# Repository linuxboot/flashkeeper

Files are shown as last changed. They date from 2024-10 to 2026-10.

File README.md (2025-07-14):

# Flashkeeper

## Manage and Protect your SPI Flash Chip!

[Documentation](https://flashkeeper.org) | [Source](https://git.15h.org/Flashkeeper/flashkeeper) | [Join us on Matrix!](https://matrix.to/#/#flashkeeper:matrix.org)

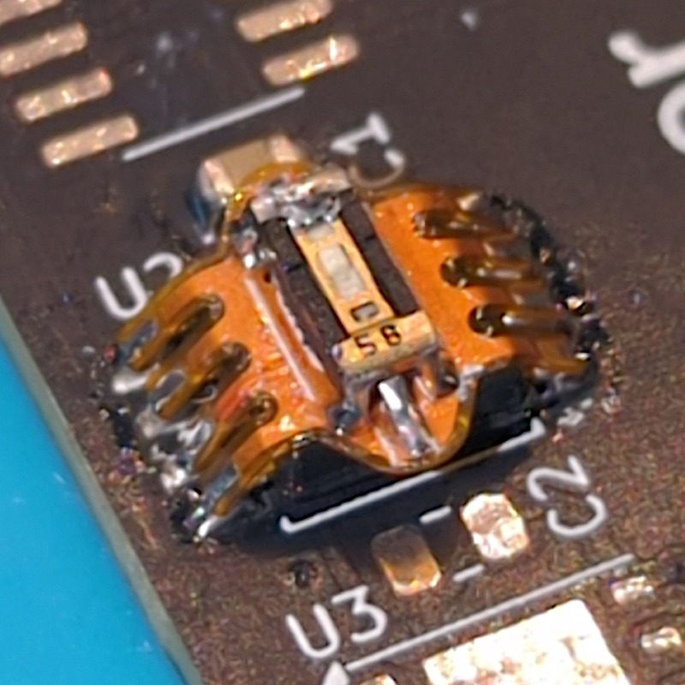
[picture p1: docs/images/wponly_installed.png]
A Flashkeeper WP provides a write-protection control switch on top of a SOIC-8 flash chip


Flashkeeper is a family of open-hardware add-ons for standard SOIC-8 and WSON-8 SPI NOR flash chips (as are commonly used for firmware storage in PCs and other electronics), providing functionality for write-protection control, SPI bus breakout, flash device emulation, reprogramming, and state validation.

Flashkeeper development takes place on the [15h.org](https://15h.org) Git forge, and is mirrored to Github as a backup. If you wish to participate in Flashkeeper development on 15h.org infrastructure, please request an account in either the [Flashkeeper room](https://matrix.to/#/#flashkeeper:matrix.org) or the 15h.org room on Matrix. Issues may be opened on either 15h.org or Github.

For user information, please see the [documentation](https://flashkeeper.org). For hardware source files, see `hw/`.

The Flashkeeper project is supported by [NLnet NGI Zero Core](https://nlnet.nl/project/Flashkeeper/).

---

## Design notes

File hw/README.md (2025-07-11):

# Flashkeeper Hardware
For source of the Flashkeeper website, see https://github.com/linuxboot/flashkeeper.

`adapter_soldered`: KiCAD files for the soldered Flashkeeper chip adapter

`dummy_board`: Rigid PCB with multiple flash package footprints and connectors for testing and development

`spispy_board`: FPGA-SoM-based board to run `spispy` during development

`single_stencil`: Project containing all PCBs in a single file. Intended to export a single paste-layer Gerber so that all Flashkeeper boards can be made using different parts of a single solder paste stencil.

`CAD`: FreeCAD files for Flashkeeper mechanical components

`flashkeeper.kicad_sym`: Symbol library for components used in Flashkeeper

`flashkeeper.pretty`: Footprint library for components used in Flashkeeper

KiCAD and FreeCAD files are for the latest upstream versions of KiCAD and FreeCAD, as of the last modification of that file. Depending on which versions your OS's packages ship, on some platforms (like Debian), this may mean installing from another repository (e.g. Debian Backports), or using an alternative packaging system such as Flatpak or AppImage. Please follow the installation instructions for your platform here:

- https://www.kicad.org/download/

- https://www.freecad.org/downloads.php

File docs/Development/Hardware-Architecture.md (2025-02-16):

---
layout: default
title: Hardware Architecture
permalink: /Hardware-Architecture/
nav_order: 99
parent: Development
---

Hardware Architecture
{: .fs-8 .m-0 }

Flashkeeper's hardware is a modular system, able to be configured for a variety of SPI flash chip security, debugging, and management tasks. Depending on their goals, most users will not need to use every part of the system. This page lists and describes the components of the Flashkeeper system, as well as the major electronic components selected for use in them, and describes some practical combinations of different Flashkeeper components. Much of this document describes "feasibility and selection" research completed before work on Flashkeeper hardware in earnest had begun - as such, it may refer to work already performed (i.e. design of various chip adapters) in the future tense.

<!-- markdownlint-disable MD033 -->
 <details open markdown="block">
   <summary>
     Table of contents
   </summary>
   {: .text-delta }
 1. TOC
 {:toc}
 </details>
 <!-- markdownlint-enable MD033 -->

Components
---
### Chip Adapter

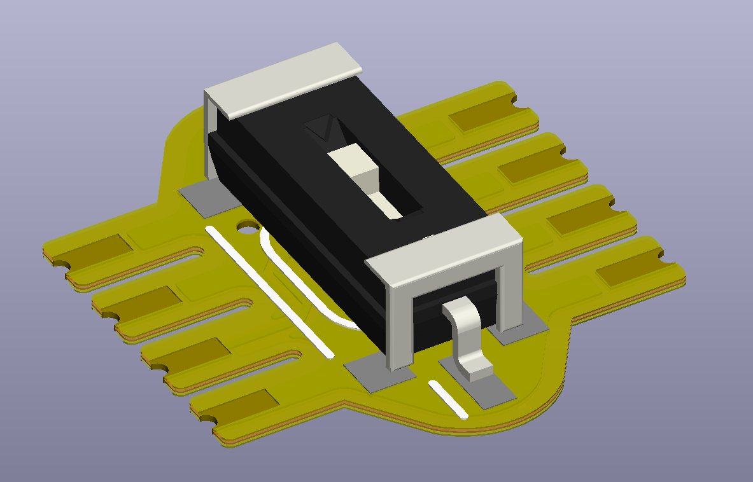
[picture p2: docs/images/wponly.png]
design


A small flex PCB which installs semi-permanently on top of an SPI flash chip. Provides control over write protection, and a breakout of the SPI bus to external devices. A flash adapter can be:

- Soldered or Solderless
- SOIC-8, WSON-8, SOIC-16, or DIP (SOIC-8 and WSON-8 are the priorities at this time, due to being the most common types)
- WP-only (providing only a switch or a jumper for write-protect control) or Breakout (with a ZIF socket, for all other uses)

As the chip adapter is electrically very simple, across all chip adapter variants, only a handful of components need to be selected:

- DIP switch for WP variants: Nidec CVS-01TB (seemingly the smallest, lowest-profile single DIP switch available)
- Spring-loaded contact for solderless variants: Harwin P70-7000045 (a rare example of a low-profile spring-loaded contact small enough to fit in a 1.27mm pitch)
- Connector for Breakout variants: TBD

### Flex Cable
A simple straight-through flex cable which runs from Breakout variants of the chip adapter to other devices, inside or outside the chassis. Connectors should be selected such that commercially-available cables can be used.

### External Breakout Board
A board intended for use outside the system, connected to the breakout cable. Useful to connect your SPI flash chip to to devices including:

- External flash programmers (e.g. CH341a), for conventional flashing/unbricking
- Development hardware such as logic analyzers or external (i.e. not the Flashkeeper FPGA Board) FPGA hardware
- The External Flash Emulator

It also allows an alternate use of the flex able, interfacing with the Flashkeeper FPGA board, as opposed to the Chip Adapter. In this role, it can be used as a USB interface board for the FPGA board, for FPGA development and authenticated reprogramming.

### External Flash Emulator
The External Flash Emulator is a development tool intended to be connected to the breakout Chip Adapter via the flex cable. It runs SPIspy and has enough memory to fully emulate the SPI flash chip, and is intended primarily as a development/diagnostic tool.

### Flashkeeper FPGA Board
The Flashkeeper FPGA is a (very) small board using the Lattice iCE40UP5K, to be installed inside the system. It provides authenticated external reprogramming (via the breakout board), and can also be used to verify flash contents in-situ (similar to the functionality of Intel's Boot Guard, but under user control). Major components of the FPGA board include:

- FPGA: Lattice iCE40UP5K-UWG30
- 1.2V Voltage Regulator: TI TPS7A2012PYCJR
- 1.8V Voltage Regulator: onsemi NCP110AFCT180T2G
- FPGA Flash Chip (firmware only - gateware burned to NVCM): BYTe BY25Q20BLRIG(R)
- Connector: Integrated flex PCB edge connector (goes into chip adapter)

It also would be possible to implement an FPGA board that was itself part of a chip adapter. This would likely reduce overall size (avoiding the connector), and situate the FPGA closer to the flash chip itself (possibly assisting some physical security mitigations), but it would of course require more permutations of FPGA boards. For now, it's not the plan.

Modularity
---
Practical configurations of Flashkeeper hardware, and their applications, include:

- Chip adapter only (either type - soldered or solderless)
	+ Add write-protection control to a flash chip on a board which does not have one
	+ Enforce partial write-protection (e.g. for Coreboot bootblock only) while allowing the remainder of flash to be updated
- Chip adapter, flex cable, breakout board
	+ Chip adapter only features
	+ Connect an external programmer (e.g. CH341a) to flash, read flashconsole, etc, without disassembling system
	+ Debug SPI with a logic analyzer
- Chip adapter, flex cable, breakout board, external flash emulator
	+ Run SPISpy (full-memory external flash emulator)
		* Rapidly-reprogrammable emulated flash for development
		* "tcpdump-style" debugging
		* Security experiments (e.g. ME TOCTOU)
- Chip adapter, Flashkeeper FPGA board, flex cable, breakout board
	+ Flashkeeper FPGA development
	+ Authenticated external reprogramming (FPGA authenticates rewriting the flash chip against a user key it holds)
- Chip adapter, Flashkeeper FPGA board (no breakout)
	+ Boot-time firmware verification
	
Depending on a user's goals, they are unlikely to require all of these configurations, and so may want to use only some components of the Flashkeeper hardware ecosystem.

Mechanical Design
---
Most Flashkeeper hardware is relatively conventional mechanically, apart from the severe size constraints on hardware inside the chassis. It consists mostly of ordinary rigid and flex PCBs. The exception to this is the solderless chip adapter, which needs to maintain contact with the _top_ of its flash chip's legs, without soldering, in a reliably-installable way. 

Without resorting to custom-designed-and-manufactured contacts, we're left with few options. The most practical, as far as we can tell, is the Harwin P70-7000045. It fits - it's low-profile, and it's narrow enough to fit into the 1.27mm lead pitch of common SMT flash chip packages, but it's a tight squeeze. 

The plan is to solder eight such contacts (each themselves a surface-mount part) to a thin rigid PCB, precisely-aligned. To assist repeatability, and to avoid contact between adjacent contacts (as the gap between them is nominally only 0.21 mm), we've designed a machined aluminum alignment block, with 8 holes drilled in the correct pattern, which can hold the pins in place, then be removed after soldering. After the alignment block is removed, a 3D-printed "adapter body" can then be pressed down over the pins and attached with adhesive to the "bottom" of the adapter PCB, around where the contacts are joined to it. This adapter body serves to insulate the contacts from eachother, and to hold them in alignment above the chip legs. It will need to be SLA 3D-printed at high resolution.

The rigid PCB should then be able to be designed much like the soldered adapter's flex PCB, with either a breakout connector, or a WP control switch.

To attach the solderless adapter to the top of the flash chip, a peel-and-stick adhesive layer will need to be applied to the bottom of the adapter body. Attachment to the flash chip relies on this layer properly adhering the adapter to the top of the flash chip, against the spring force of its contacts. It will be important to instruct the user on the proper cleaning of their flash chip, and on the proper application of the adapter. For example, installation repeatability could be aided by a 3D-printable handheld plunger-style force gauge, helping the user apply the right amount of force to the adhesive for the right duration to adhere it properly without risk of damage.

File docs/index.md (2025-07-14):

---
layout: default
title: Home
has_children: true
has_toc: false
permalink: /
nav_order: 1
---

# Manage and Protect your SPI Flash Chip!

Flashkeeper is a family of open-hardware add-ons for standard SOIC-8 and WSON-8 SPI NOR flash chips (as are commonly used for firmware storage in PCs and other electronics), providing functionality for write-protection control, SPI bus breakout, flash device emulation, reprogramming, and state validation.

wponly
*The WP-only adapter provides a physical write protection switch for [flash chips supporting WP](https://github.com/linuxboot/flashkeeper/pull/14/files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)*

<!-- markdownlint-disable MD033 -->
<details open markdown="block">
  <summary>
    Table of Contents
  </summary>
  {: .text-delta }
1. TOC
{:toc}
</details>
<!-- markdownlint-enable MD033 -->

## For Users
Flashkeeper is a modular family of several related devices - to find out which components you need, and where to get them, see [Getting Started](/Getting-Started).

## For Developers
Flashkeeper development takes place on the [15h.org](https://15h.org) Git forge, and is mirrored to Github as a backup. If you wish to participate in Flashkeeper development on 15h.org infrastructure, please request an account in either the [Flashkeeper room](https://matrix.to/#/#flashkeeper:matrix.org) or the 15h.org room on Matrix. Issues may be opened on either 15h.org or Github.

## More about Flashkeeper

* [Flashkeeper threat model]({{ site.baseurl }}/Flashkeeper-threat-model/) - goes into more detail about what classes of threats Flashkeeper attempts to counter.
* [Frequently Asked Questions]({{ site.baseurl }}/FAQ/)
* [Prior Art/State of the Art prior of project start](https://cfp.3mdeb.com/qubes-os-summit-2024/talk/FCENX9/)

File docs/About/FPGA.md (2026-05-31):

---
layout: default
title: FPGA Module
permalink: /FPGA
nav_order: 9
has_children: no
has_toc: true
---

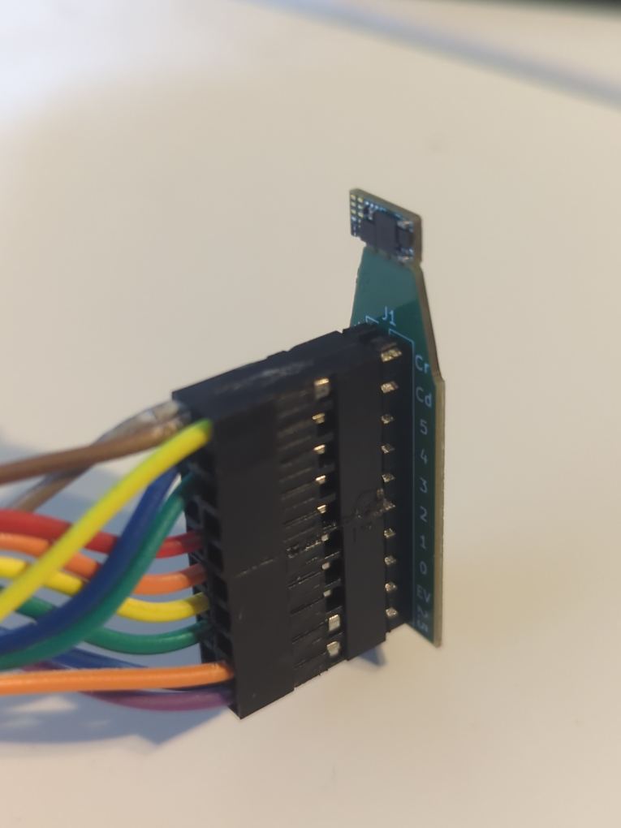
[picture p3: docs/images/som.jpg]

*The Flashkeeper SoM (top), attached to its removable breakout tab with a standard 2.54mm pin header*

# Introduction
The Flashkeeper FPGA module is special variant of the Flashkeeper chip adapter, designed to interface your SPI flash chip with a specialized Flashkeeper system-on-module (SoM) based on a Lattice iCE40UP5K FPGA. The Flashkeeper FPGA module is a general-purpose computer, under full, RTL-level user control, and designed for a wide range of security, development, and flash device management tasks. In addition to its RISC-V soft core and the hardware reconfigurability afforded by any FPGA, it also features 4 Mbit of NOR flash, 128 kB of main SRAM, one-time programmable NVCM, flexible SPI, UART, and I2C peripherals, a software-controllable buzzer for alerts and acoustic communications, an integrated real-time clock with battery and crystal, and onboard power regulation and filtering for all required voltage rails, including battery charging, from the single power rail on the host flash chip package.

<!-- markdownlint-disable MD033 -->
<details open markdown="block">
  <summary>
    Table of Contents
  </summary>
  {: .text-delta }
1. TOC
{:toc}
</details>
<!-- markdownlint-enable MD033 -->

## System Compatibility
The Flashkeeper FPGA module is designed for use on most standard 8-pin NOR flash packages, including most SOIC-8 and WSON-8 variants. The module body, excluding its attachment legs, measures 4.7 x 7.5 mm, and the entire module, when fully folded, stands 6.0mm above the surface of the host flash chip, including its "tail" section (which contains the battery, buzzer, and associated components). In many systems, it can be installed in this folded configuration, with a footprint only negligibly larger than the flash chip itself. Unfolded, it requires only 2.6mm of vertical space above the flash chip, allowing the tail to sit beside the host flash chip.

The folded configuration is recommended for:
* Nearly all desktop and server platforms
* Laptops with sufficient space between motherboard and chassis
* Open-air usage (SBCs, development boards, bench testing, etc)

The unfolded configuration is recommended for: 
* Small-form-factor desktop systems with back-mounted SPI flash chips
* Most laptops - fit checks have been performed on various Lenovo ThinkPad X-series (including X220, X230, X140e)
* Systems where the debug ribbon cable is to remain easily-removable (for external flashing, wired verification, development, etc)

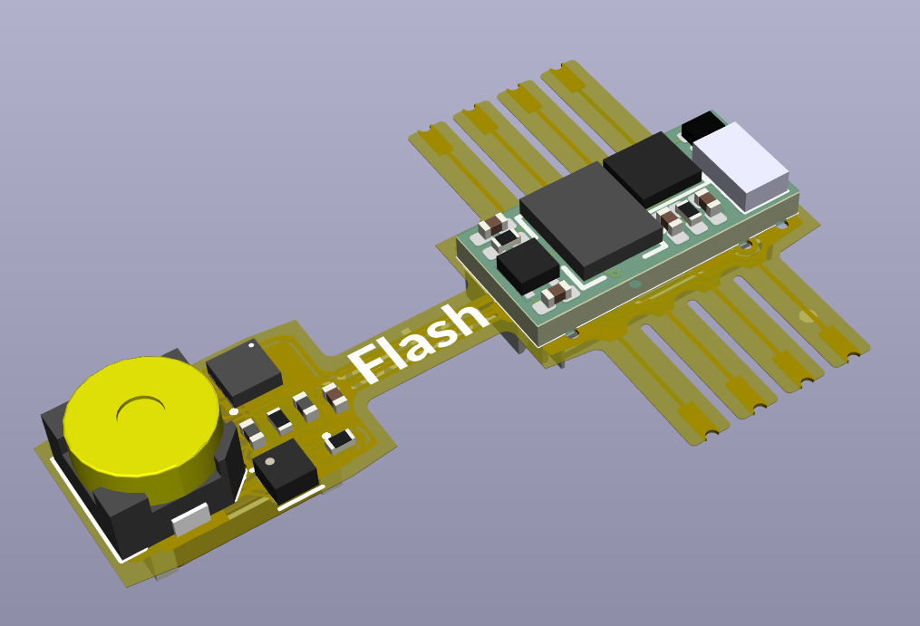
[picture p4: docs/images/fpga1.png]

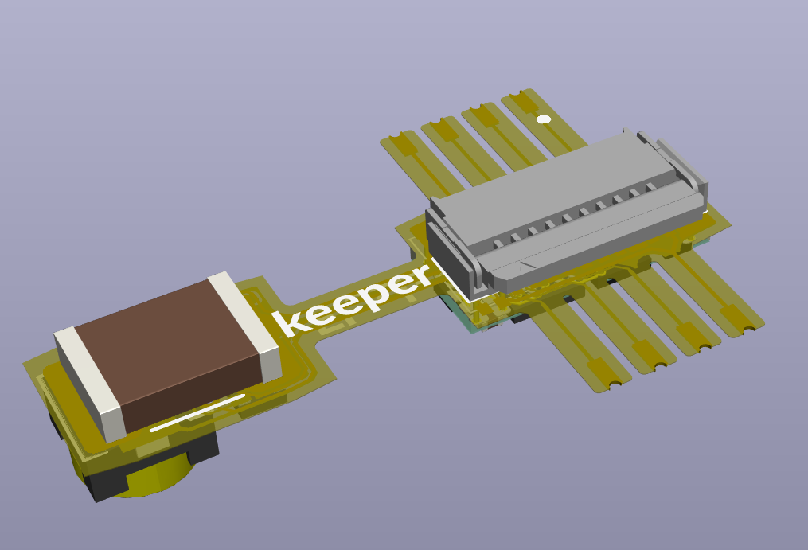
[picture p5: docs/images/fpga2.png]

*The tail section (left) can be folded over the chip adapter body (right), or can be laid to the side, depending on chassis or board obstructions*

The Flashkeeper FPGA draws approximately 9 mA while running, and can be installed with negligible power or thermal impact in virtually any computing device with a SOIC or WSON flash chip - for comparison, many SPI flash chips themselves can consume up to 25 mA while being erased and programmed during a firmware update. All systems we have evaluated for this have had more-than-sufficient current for the module available at the flash package.

The FPGA is only powered when the host SPI flash is, and should not meaningfully contribute to system battery drain in storage. When the host is powered on, Flashkeeper's real-time clock battery is trickle-charged by a dedicated low-power charging circuit. In order keep the RTC battery charged, host systems should be powered on for at least 2-3 hours per month if Flashkeeper's real-time clock is required. A diode prevents the RTC battery from discharging into the rest of the SoM, or into the host, when host power is unavailable.

On systems using 1.8V SPI flash, the module is able to generate most of its voltages from 1.8V, but the FPGA itself requires a 2.5-3.3V rail for its internal oscillator and one-time programmable memory. Even on systems with 1.8V flash, 3.3V power is usually available nearby on the motherboard and can be relatively easily wired to the module during installation - a solder jumper and designated pad on the module are provided for this use.

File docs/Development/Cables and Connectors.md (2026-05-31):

---
layout: default
title: Cables and Connectors
permalink: /Cables-Connectors/
nav_order: 99
parent: Development
---

Cables and Connectors
{: .fs-8 .m-0 }

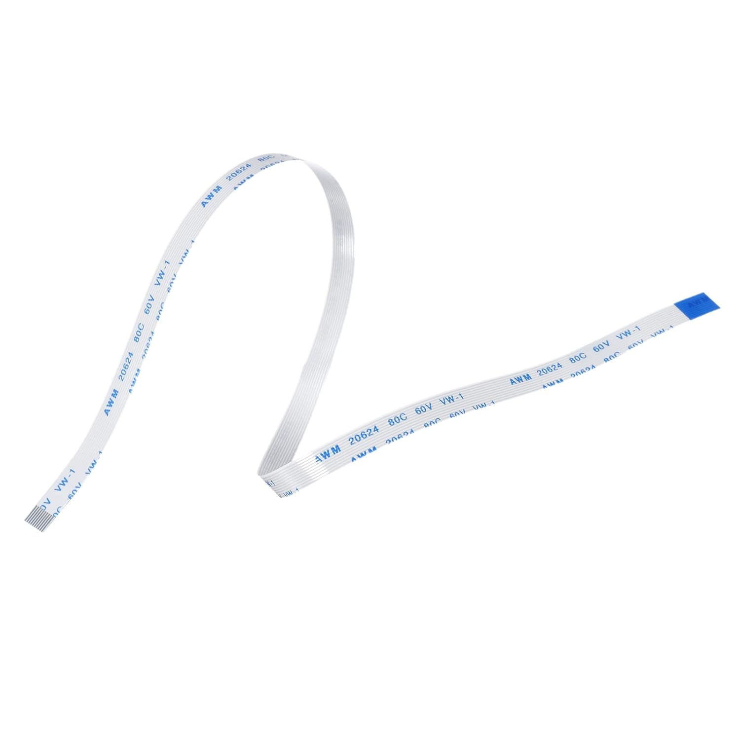
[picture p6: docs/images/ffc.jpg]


Flashkeeper has standardized on two common types of flat-flex cable (FFC) - one for Flashkeeper FPGA hardware, one for breakout chip adapters. All FFCs used by Flashkeeper are standard 0.5mm pitch B-type (opposite-side-contact) cables, as are commonly used in laptops and other consumer electronics. Lengths between 1cm and 50cm are widely and inexpensively available online from websites such as [AliExpress](https://www.aliexpress.com/w/wholesale-0.5mm-b%2525252dtype-ffc.html?spm=a2g0o.productlist.search.0), [eBay](https://www.ebay.com/sch/i.html?_nkw=0.5mm+b+type+ffc), and [Amazon](https://www.amazon.com/s?k=0.5mm+b+type+ffc), and are generally interchangeable between brands. If purchasing FFCs for Flashkeeper hardware, for best signal integrity, opt for the shortest cable which will reach in your chassis.

While both are common sizes, note that cables are NOT interchangeable between Flashkeeper breakout chip adapters (including dummy boards), and Flashkeeper FPGA hardware - these devices carry different signals over different pinouts, and the FPGA hardware requires additional pins for use with the FPGA Configuration Tool.

<!-- markdownlint-disable MD033 -->
 <details open markdown="block">
   <summary>
     Table of contents
   </summary>
   {: .text-delta }
 1. TOC
 {:toc}
 </details>
 <!-- markdownlint-enable MD033 -->

---
### Breakout Chip Adapters
Flashkeeper FPGA hardware uses standard **8-pin** 0.5mm FFC, and has standardized on the TE Connectivity 2328702-8 flip-lock connector. If you wish to design flash device breakout hardware to be interoperable with Flashkeeper breakout hardware, the pinout is provided below - note that "pin 11" refers to the front grounding tabs of the connector, and does not appear on the cable itself.

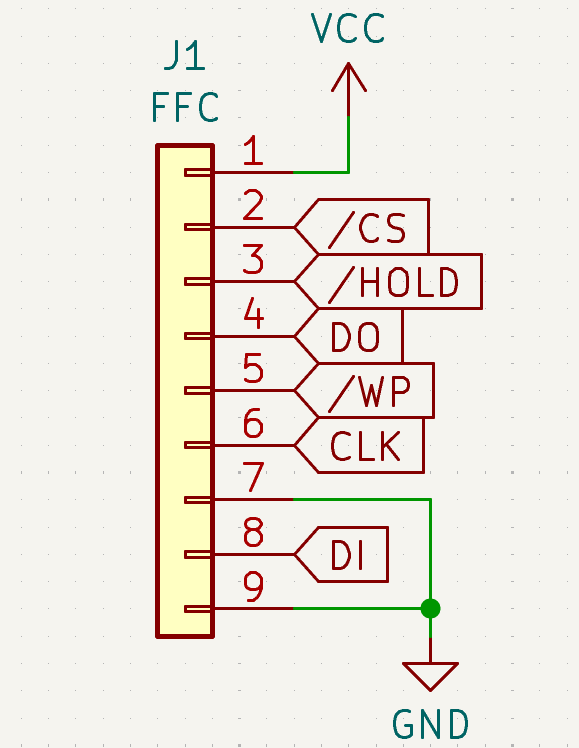
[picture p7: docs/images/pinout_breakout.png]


### FPGA Hardware
Flashkeeper FPGA hardware uses standard **10-pin** 0.5mm FFC, and has standardized on the TE Connectivity 1-2328702-0 flip-lock connector. If you wish to design sensors, adapters, or other peripherals to be interoperable with Flashkeeper FPGA hardware, the pinout is provided below - note that "pin 9" refers to the front grounding tabs of the connector, and does not appear on the cable itself.

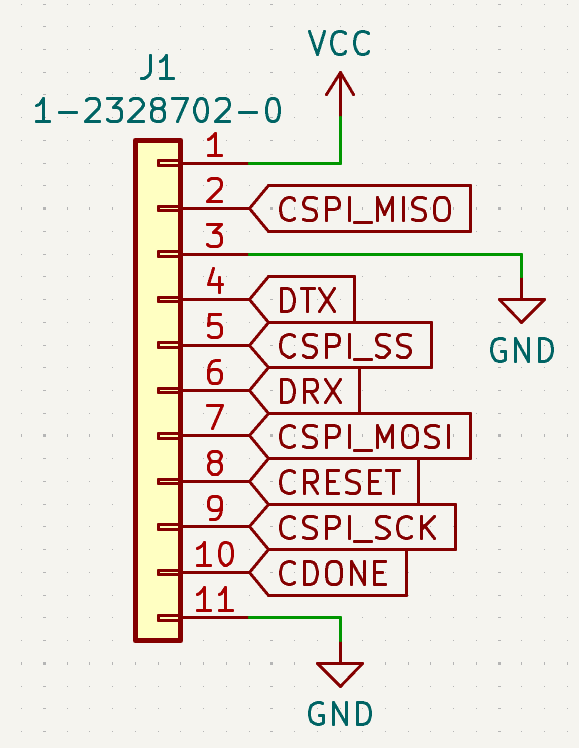
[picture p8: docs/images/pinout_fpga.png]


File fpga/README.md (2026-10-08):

# Flashkeeper FPGA

Gateware and firmware for the iCE40UP5K FPGA on the Flashkeeper FPGA module, using PicoSoC and the PicoRV32 RISC-V core.

For KiCAD source for the Flashkeeper FPGA hardware, see hw/fpga

## SoC Features
- PicoRV32 RV32IZmmul CPU - hardware multiply, software divide (picorv32.v)
- Modified PicoSoC (picosoc.v)
- 128 KiB RAM (iCE40UP5k SPRAM - ice40up5k_spram.v)
- EBR-based bitstream Boot ROM (can be OTP-programmed as part of NVCM - ebrrom.v)
- Configuration (CSPI) and Host (HSPI) SPI flash interfaces (spimemio.v)
- Buffered UART serial interface (uart.v)
- Entropy source for TRNG (rng.v)
- On-chip (HFOSC) clock source for crystal-less Flashkeeper FPGA SoM (top.v)

## Firmware Features
- Forth-like Embedded Debug Environment shell (ede.h)
- Diagnostics and flash device management via serial interface (type help at EDE)
- Boot-ROM-based firmware loading and verification from flash (rom/)
- Cryptography provided by TweetNaCl (tweetnacl.c)
- High-speed libsodium-based ed25519 verifcation (fwsiglib)
- Serial password authentication support (main.c - password_prompt, generate_password)
- flashrom-compatible serprog emulation mode (serprog.c)
- Software-based entropy extraction and RNG monitoring (rng.c)

## Build Dependencies
On Debian, install:
```
sudo apt install yosys nextpnr-ice40 fpga-icestorm gcc-riscv64-unknown-elf
```

## Building and Flashing
To build an image for the Flashkeeper SoM development kit, run `make som_image`. To flash it to the SoM using flashrom
and a standard CH341a SPI flash programmer, run `make prog_flash_som`. During flashing, this target will attempt to hold
the FPGA in reset using an ESP-PROG (which can be used as a USB serial interface for a standalone Flashkeeper SoM).

Targets and pin mappings are also provided for use with the official Lattice iCE40 UltraPlus Breakout Board (iCE40UP5K-B-EVN),
which has an onboard FT2232HL-based debug interface. To program this board using iceprog, run `make prog_flash_breakout`.

## Firmware Signing
By default, these Makefiles will attempt to generate a signed firmware image, and will enable firmware signature verification in the
Boot ROM. This requires a keypair to sign your firmware image - you can generate one with:
```
make -C firmware tools/genkey
firmware/tools/genkey firmware/keys/pk.key firmware/keys/sk.key
```
After generating your keypair, the build will automatically sign your firmware using your secret key (sk.key), and your built Boot ROM
will automatically include your public key (pk.key) and use it to verify your signed firmware images at boot.

If you wish to build an *unsigned* firmware image, you can build with `SIGN=0`. By default, the Boot ROM will reject unsigned images - to
build a Boot ROM allowing unsigned images, also build with `ROM_ALLOW_UNSIGNED=1`. For example, to build an unsigned image and a Boot ROM
that will accept it, for the Flashkeeper FPGA SoM, you can run:
```
make som_image SIGN=0 ROM_ALLOW_UNSIGNED=1
```
Of course, a boot ROM built with ROM_ALLOW_UNSIGNED provides **no protection against firmware tampering**, and should be used for development
only. A ROM_ALLOW_UNSIGNED Boot ROM can still boot signed firmware images (in addition to unsigned ones), and will still attempt to verify
a firmware image signature if one is present. 

## Setting a Password
If you are using a Flashkeeper FPGA in a deployed system, we strongly recommend setting a serial password - if you do not do so,
anyone able to connect to your FPGA's UART interface can read and write both Host (your computer's) and Configuration (your Flashkeeper's)
SPI flash devices.

By default, a password is required (SERIAL_REQUIRE_PASSWORD = 1), and the default password is `flashkeeper`.
If SERIAL_REQUIRE_PASSWORD is set to 0, the FPGA will enter EDE automatically at firmware boot (with a warning to set a password).

To set a password, run `genpw` at the Flashkeeper EDE shell (connected over serial), then copy-and-paste the resulting two lines into
firmware/flashkeeper_config.h, then rebuild and reflash your Flashkeeper firmware image (as described above).

## Boot Process
The Flashkeeper FPGA SoM has its own onboard 4 Mbit (512 kB) SPI flash chip (CSPI), which holds its FPGA bitstream and firmware.
The RISC-V reset vector and early boot is in boot ROM (in the FPGA's EBR, preloaded as part of the FPGA bitstream). The ROM is
firmware-independent (the image header in flash describes the image, so the ROM should not need to be rebuilt for firmware
changes). The Boot ROM's boot and firmware verification process is as follows:
- Load the firmware image from CSPI flash into RAM
- Confirm its IMG_MAGIC and size are valid
- Load a binary called fwsiglib from an extra region of CSPI flash after the firmware image, into a reserved SPRAM region below the stack
- Using TweetNaCl's SHA-512 (small enough to fit in the boot ROM), verify the hash of the fwsiglib binary against a hash built into the boot ROM
- If fwsiglib is valid, check if the loaded firmware image claims to be signed by the right public key
- Hash the firmware image in RAM's payload
- Using fwsiglib, check the firmware image's embedded ed25519 signature of its header and payload hash against its actual header and payload hash
- If correct, jump to the image's payload entry point.

## Licensing
Unless stated otherwise, developments of the Flashkeeper project are licensed under the GNU General Public License
Version 3.

serprog.c and serprog.h are derived from pico-serprog, developed by Mate Kukri and originally based on code by Thomas Roth.
pico-serprog is also licensed under the GNU General Public License Version 3.

Files originating with the PicoRV32 are under the ISC License. They were originally developed by Claire Xenia Wolf. picosoc.v,
spimemio.v, uart.v, and ice40up5k_spram.v have been modified as part of the Flashkeeper project.

memops.S, used for certain RISC-V memory operations, is under the 2-clause BSD license and was developed by Alexander Vysokovskikh.

libsodium ed25519 files used in the boot ed25519 library (rom/lib) are under the ISC license, and are developed by Frank Denis and
the [libsodium authors](https://raw.githubusercontent.com/jedisct1/libsodium/refs/heads/master/AUTHORS).

tweetnacl.c and tweetnacl.h are a public-domain cryptography library, and were developed by Daniel J. Bernstein,
Bernard van Gastel, Wesley Janssen, Tanja Lange, Peter Schwabe, and Sjaak Smetsers.

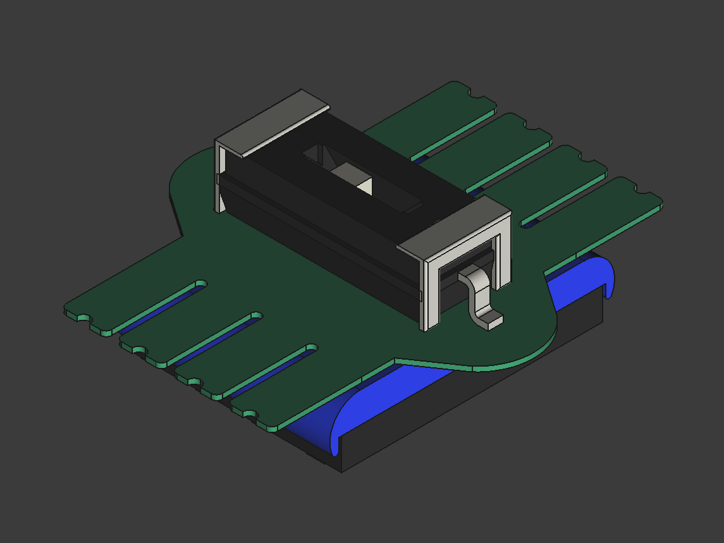
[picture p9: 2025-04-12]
docs/images/wson.png

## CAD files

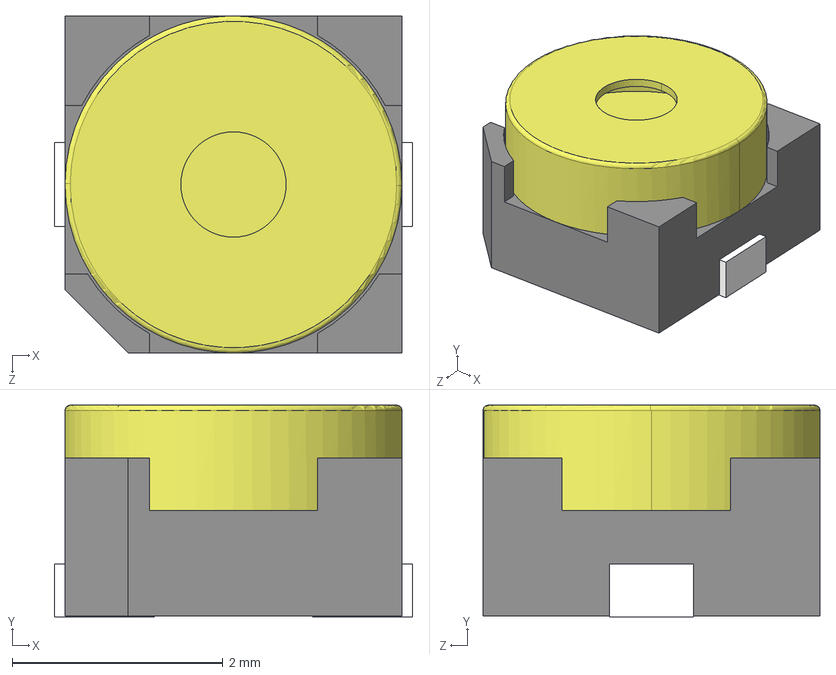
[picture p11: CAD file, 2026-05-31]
hw/CAD/CMT-322-65-SMT-TR.step
3.40 x 2.01 x 3.20 mm

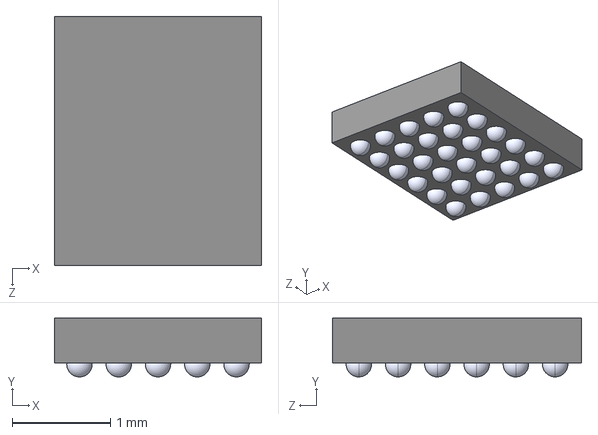
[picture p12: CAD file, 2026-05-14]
hw/fpga/ICE40UP5K-UWG30ITR/ICE40UP5K-UWG30ITR.step
2.11 x 0.6 x 2.54 mm

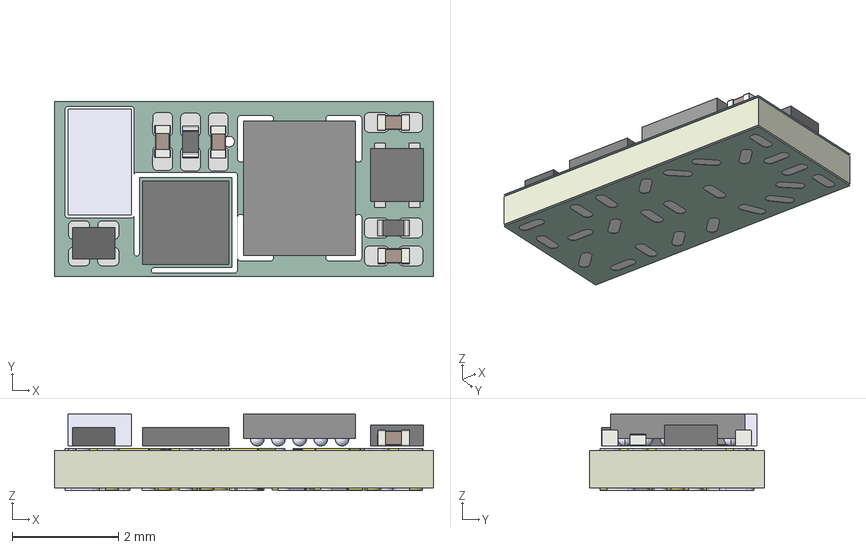
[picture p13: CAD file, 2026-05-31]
hw/CAD/FlashkeeperFPGASoM.step
7.15 x 3.30 x 1.45 mm
C_0201_0603Metric x 4
R_0201_0603Metric x 2
ICE40UP5K-UWG30ITR
fpga_notab_copper
fpga_notab_pad
fpga_notab_via
fpga_notab_silkscreen
fpga_notab_soldermask x 2
fpga_notab_PCB

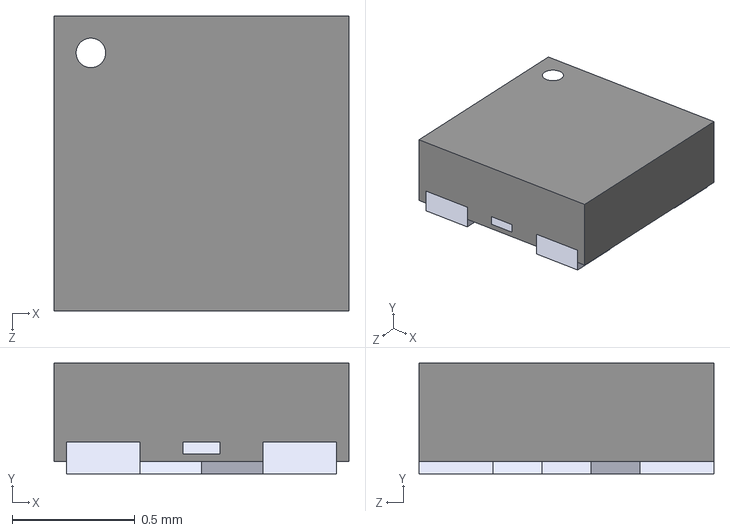
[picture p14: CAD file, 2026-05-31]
hw/CAD/NCP171AMX165160TCG.step
1.20 x 0.45 x 1.20 mm

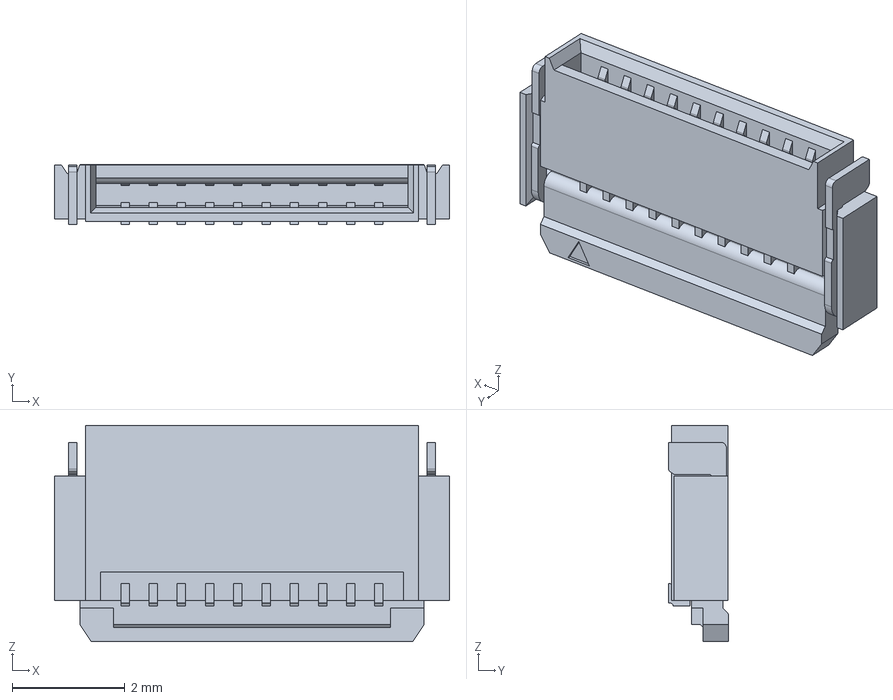
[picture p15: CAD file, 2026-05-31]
hw/CAD/1-2328702-0.STEP
7.00 x 1.06 x 3.83 mm

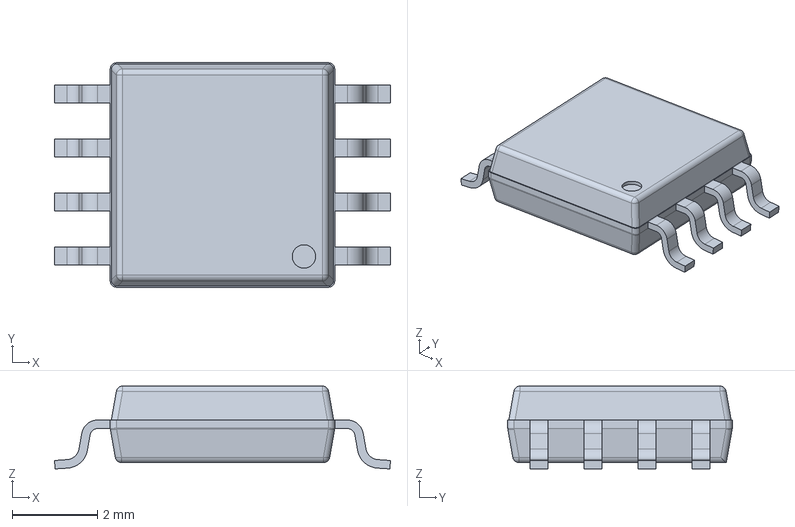
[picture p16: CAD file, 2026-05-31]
hw/CAD/SOIC8_Wide.FCStd
7.90 x 5.28 x 1.95 mm

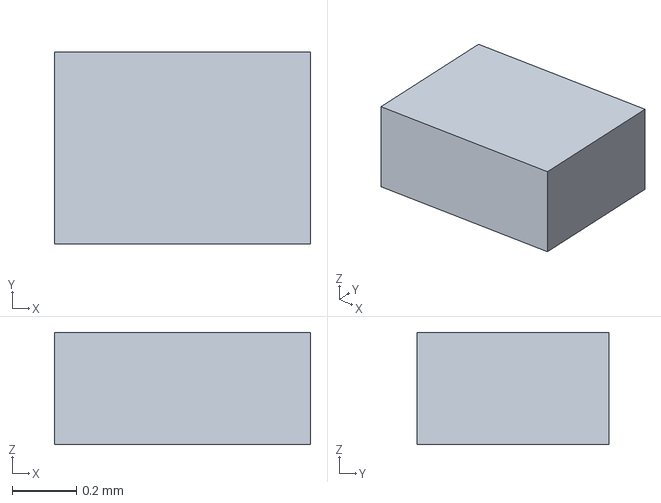
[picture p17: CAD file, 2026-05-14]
hw/CAD/Basic_YC102.step
0.8 x 0.6 x 0.35 mm

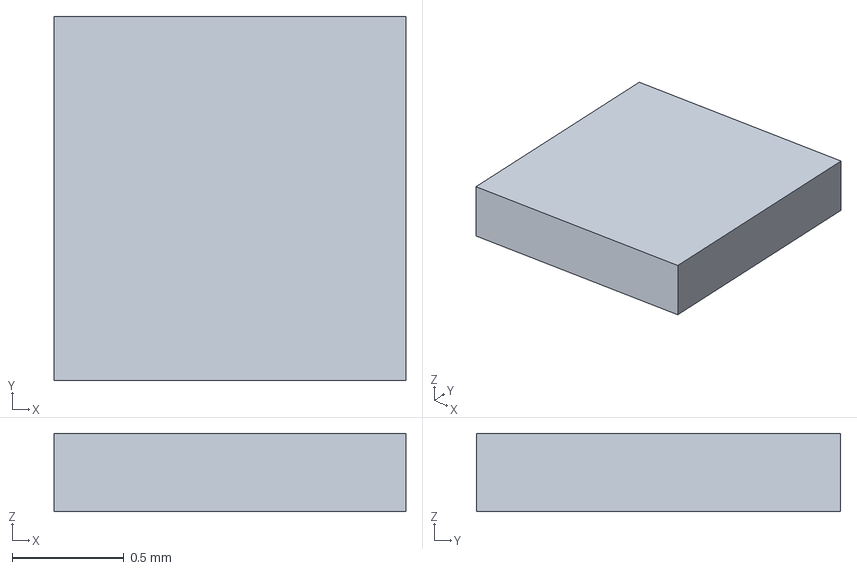
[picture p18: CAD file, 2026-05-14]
hw/CAD/Basic_AT25DF041-UUN.step
1.57 x 1.63 x 0.35 mm

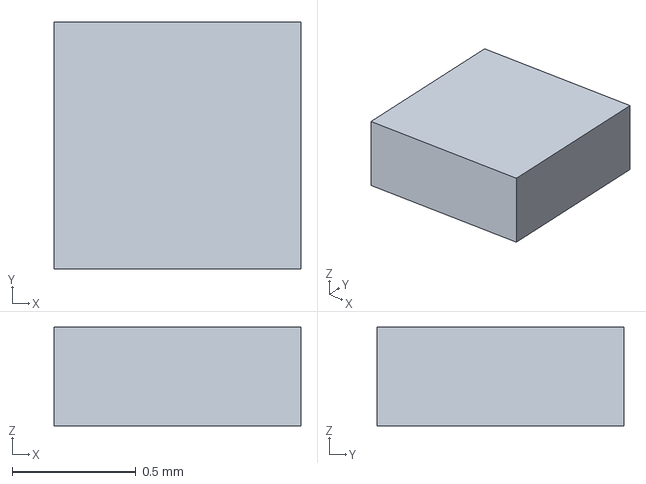
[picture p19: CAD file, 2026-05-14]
hw/CAD/Basic_X2SON.step
1.00 x 1.00 x 0.4 mm

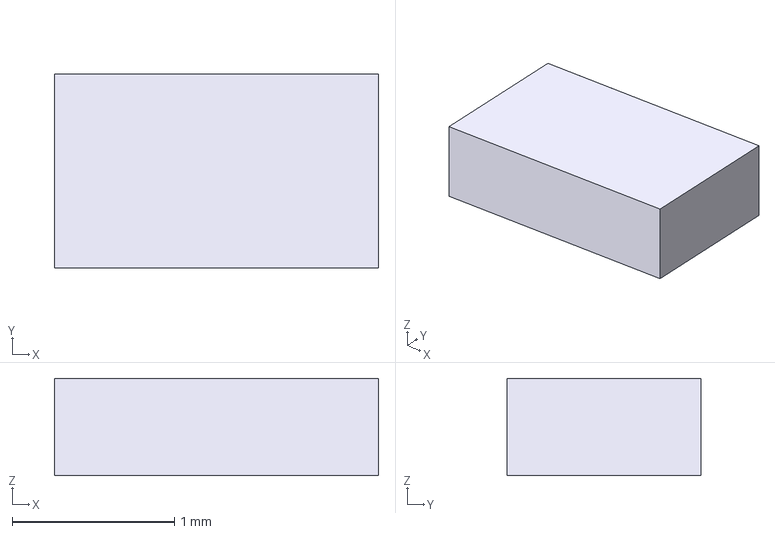
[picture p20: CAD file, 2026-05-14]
hw/CAD/Basic_RV-3028-C8.step
2.00 x 1.20 x 0.6 mm

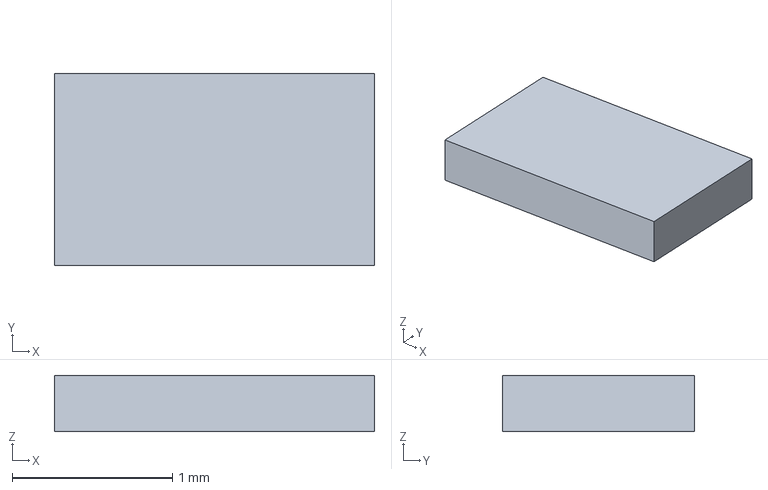
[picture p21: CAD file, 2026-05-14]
hw/CAD/Basic_AT25DF041B.FCStd
2.00 x 1.20 x 0.35 mm

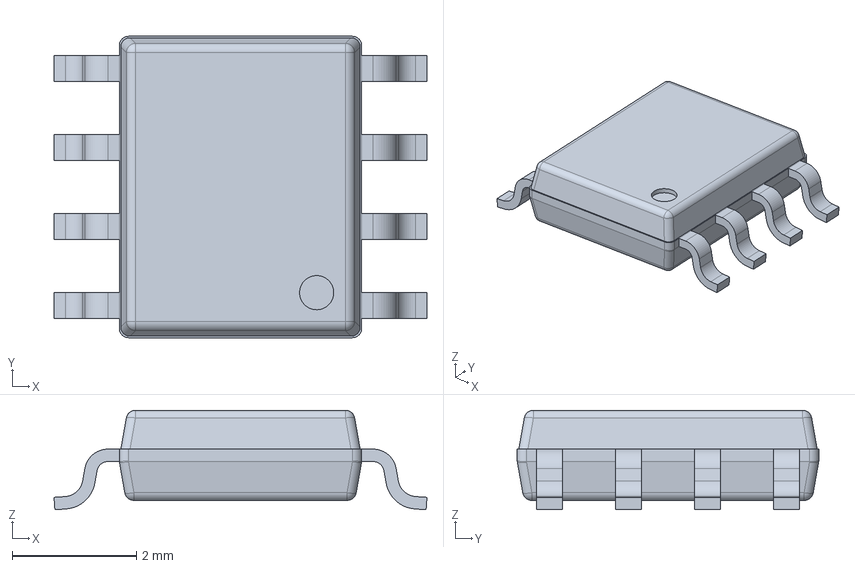
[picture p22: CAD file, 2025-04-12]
hw/CAD/SOIC8.FCStd
6.00 x 4.85 x 1.60 mm

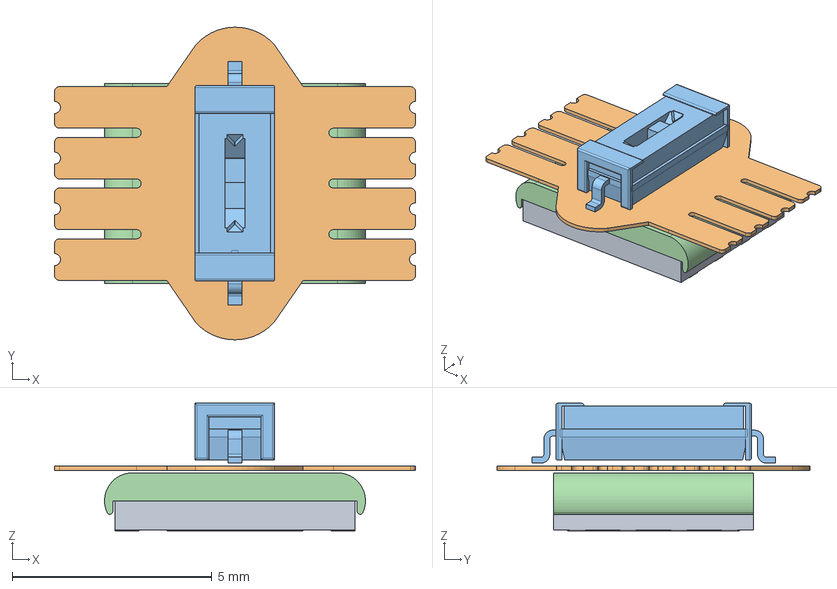
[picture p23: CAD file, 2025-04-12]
hw/CAD/WSON.FCStd
9.04 x 7.83 x 3.19 mm
Pcb_97be
SW1_SW_DIP_SPSTx01_Slide_Copal_CVS_01xB_W59mm_P1mm_5cda699ed413
InterposerBlock

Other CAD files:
hw/CAD/Basic_RV-3028-C8.FCStd
hw/CAD/Basic_X2SON.FCStd
hw/CAD/Basic_YC102.FCStd

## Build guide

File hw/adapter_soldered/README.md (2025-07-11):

# Soldered Chip Adapter

`wp_only_wide`: Write-protect-only chip adapter, controls flash chip write protect using switch or solder jumper, for wide (standard for flash chips) SOIC-8 and WSON-8.

`wp_only`: Same as above, for (rare for flash chips) "narrow" SOIC-8 packages

`breakout_wide`: Breakout chip adapter, for connecting your flash chip to external hardware (like a programmer or an SPIspy device) using a 0.5mm 8-pin FFC. For wide SOIC-8 and WSON-8.

`integrated_cable`: Experimental. Like the breakout adapter, but rather than having an FFC ZIF socket like the above, it has a short length of FFC built-in.

`adapter_soldered.kicad_pro` Overarching KiCAD project containing all variants. Use of this is optional.

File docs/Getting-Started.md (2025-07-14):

---
layout: default
title: Getting Started
permalink: /Getting-Started
nav_order: 9
has_children: no
has_toc: true
---

# Getting Started
The Flashkeeper project develops several different hardware devices for interfacing with, managing, and protecting different SPI flash devices. This page lists multiple Flashkeeper use cases, and suggests a set of devices which might be useful for each.

<!-- markdownlint-disable MD033 -->
<details open markdown="block">
  <summary>
    Table of Contents
  </summary>
  {: .text-delta }
1. TOC
{:toc}
</details>
<!-- markdownlint-enable MD033 -->

## I'm a user who wants to protect my firmware against tampering
You can use a Flashkeeper WP-only chip adapter to write-protect your flash chip. On most modern SPI flash devices, this will allow you to use [partial write-protection support in Flashrom](https://github.com/linuxboot/flashkeeper/pull/14/files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), for example to protect the Coreboot bootblock while permitting modification elsewhere. Since nearly all PC motherboards use "wide" flash chips, you will probably need the `wide` chip adapter variant. Currently, only the soldered chip adapter variants have been validated.

wponly

If your chassis provides enough space above your flash chip, consider adding the CVS-01TB DIP switch, so that you can enable and disable write-protection by hand. If it doesn't (such as in some thin laptops), or if you don't want to add the switch, you can instead bridge and unbridge the built-in solder jumper to enable and disable write-protection.

**You'll need:**
- The WP-only chip adapter for your flash chip (almost certainly [`adapter_soldered/wp_only_wide`](https://git.15h.org/Flashkeeper/flashkeeper/src/branch/main/hw/adapter_soldered/wp_only_wide))
- A Nidec CVS-01TB SMT DIP switch (if you have a "bare board" flash adapter and wish to add a mechanical WP switch to it)

## I'm a user who wants an easier way to reprogram the flash chip in my system
The breakout chip adapter allows you to extend your SPI bus off of the flash chip and over a standard 8-pin flex cable to a removable "dummy board", providing a more convenient place to connect a programmer in many chassis.

First, select a location in your chassis to run the breakout cable out of. The cable is 4.5mm wide, approximately 0.1mm thick, and can be folded and curved as necessary to reach your desired location. In desktops, the cable can often be run out the front panel or into the bottom of the case. In laptops, consider putting the end of the cable under a removable panel (such as a memory or battery hatch) so that it can be covered when not in use, or running it out between the chassis and the housing of a port (such as "on top of" a USB-A connector).

For best signal integrity (SPI buses usually operate at reasonably high frequencies), choose the shortest available cable that will reach your desired location.

**You'll need:**
- The breakout chip adapter ([`adapter_soldered/breakout_wide`](https://git.15h.org/Flashkeeper/flashkeeper/src/branch/main/hw/adapter_soldered/breakout_wide))
- A standard "reverse-order"/"B-type", 8-pin, 0.5mm pitch flat-flex cable, in the length you need. AliExpress and Amazon
- The dummy board ([`dummy_board`](https://git.15h.org/Flashkeeper/flashkeeper/src/branch/main/hw/dummy_board)), to connect your external programmer to the FFC
- An SPI flash programmer of your choice

## I'm a firmware developer who wants to test my firmware builds more efficiently

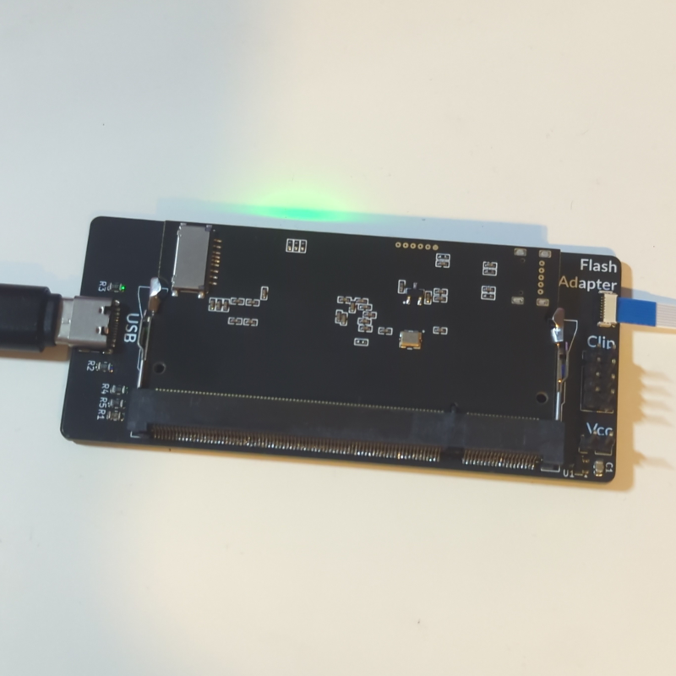
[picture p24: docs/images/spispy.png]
spispy


The SPI Emulator and Probe (aka "SPIspy board") is a development tool which allows you to emulate an SPI flash chip using [SPIspy](https://github.com/osresearch/spispy). The flash image is held in RAM on the FPGA, allowing it to be reprogrammed over USB far more rapidly than programming a conventional SPI flash chip. It's designed to connect to a breakout chip adapter over the same FFC it usually uses, or to a standard Pomona clip (via a standard 2.54mm-pitch jumper wire header).

For more information on SPIspy with Flashkeeper, see the [spispy_flashkeeper](https://git.15h.org/Flashkeeper/spispy_flashkeeper) repository.

**You'll need:**
- The SPI Emulator and Probe ([`spispy_board`](https://git.15h.org/Flashkeeper/flashkeeper/src/branch/main/hw/spispy_board))
- An interface to your flash chip, either:
  - The breakout chip adapter ([`adapter_soldered/breakout_wide`](https://git.15h.org/Flashkeeper/flashkeeper/src/branch/main/hw/adapter_soldered/breakout_wide))
  - A standard "reverse-order"/"B-type", 8-pin, 0.5mm pitch flat-flex cable, in the length you need. AliExpress and Amazon
- or,
	- A standard Pomona-style "chip clip"
	- Appropriate 2.54mm-pitch cabling to connect it to a 2.54mm-pitch pin header

## I want to experiment with various flash chip packages, or to adapt a modern flash chip to an old motherboard

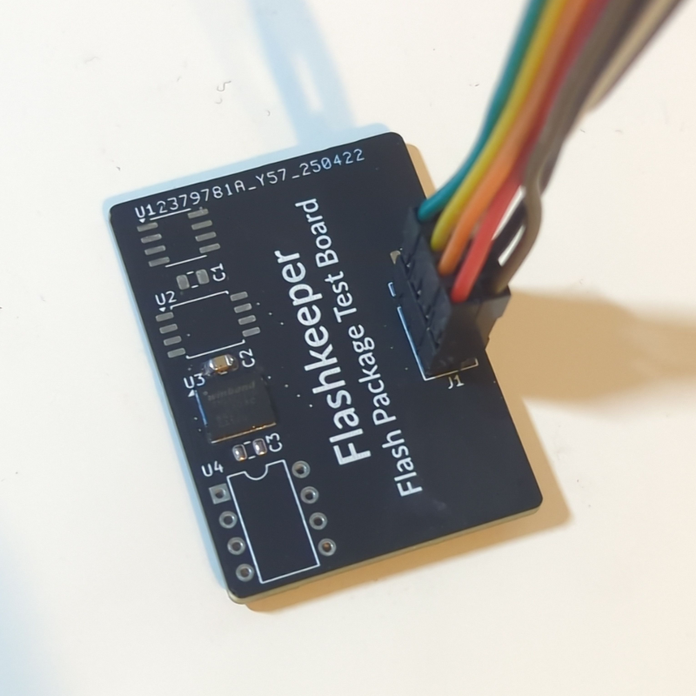
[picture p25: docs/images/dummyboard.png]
dummy


The Flash Package Test Board (aka "dummy board") was initially developed for testing other Flashkeeper hardware, but has turned out to be quite a useful adapter in its own right. It's simple PCB, with flash package footprints for narrow and wide SOIC-8, 5x6mm WSON-8, and DIP-8, as well as a standard 2.54mm pin header and (on newer versions) an 8 pin FFC ZIF socket (to connect to the SPI Emulator and Probe or the Breakout Adapter). By adding two pin headers, it can be used as a SOIC/WSON to DIP-8 adapter (for older motherboards such as the KGPE-D16 which use DIP flash chips).

By soldering a SOIC-8 ZIF socket onto its SOIC-8 Wide footprint, the board can also be used to program loose SOIC flash chips, such as during manufacturing. Either connect it to a programmer via one of its connectors, or attach a pin header to its DIP footprint and place the entire dummy board, socket and all, into the DIP ZIF socket on your programmer.

On DIP motherboards, the dummy board can also be used as either types of chip adapter - to WP your flash chip (like the WP-only chip adapter), connect a jumper between the WP and GND pins of the 2.54mm header. To extend your SPI bus over an FFC (like the breakout chip adapter), use either that header or the FFC ZIF socket with a cable of your choosing.

**You'll need:**
- The dummy board ([`dummy_board`](https://git.15h.org/Flashkeeper/flashkeeper/src/branch/main/hw/dummy_board))
- (likely) an SPI flash programmer (e.g. CH341a)
- Additional hardware of your choosing, for your application

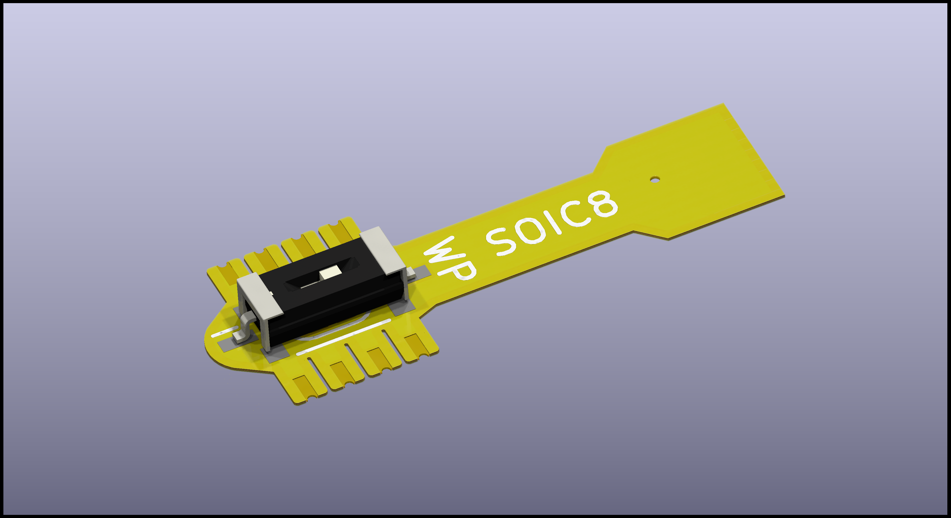
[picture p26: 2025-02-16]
hw/adapter_soldered/integrated_cable/adapter_soldered_top.png

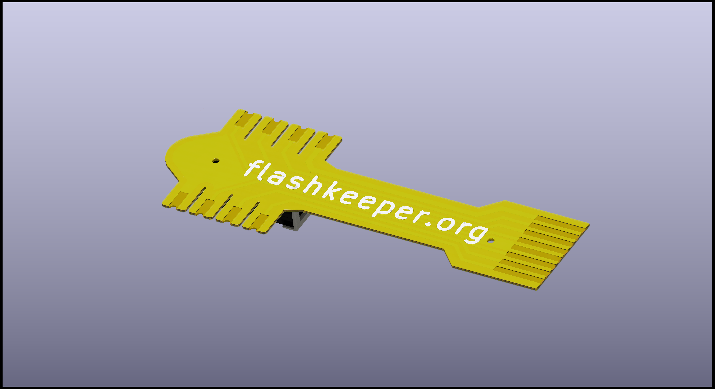
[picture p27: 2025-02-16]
hw/adapter_soldered/integrated_cable/adapter_soldered_bottom.png

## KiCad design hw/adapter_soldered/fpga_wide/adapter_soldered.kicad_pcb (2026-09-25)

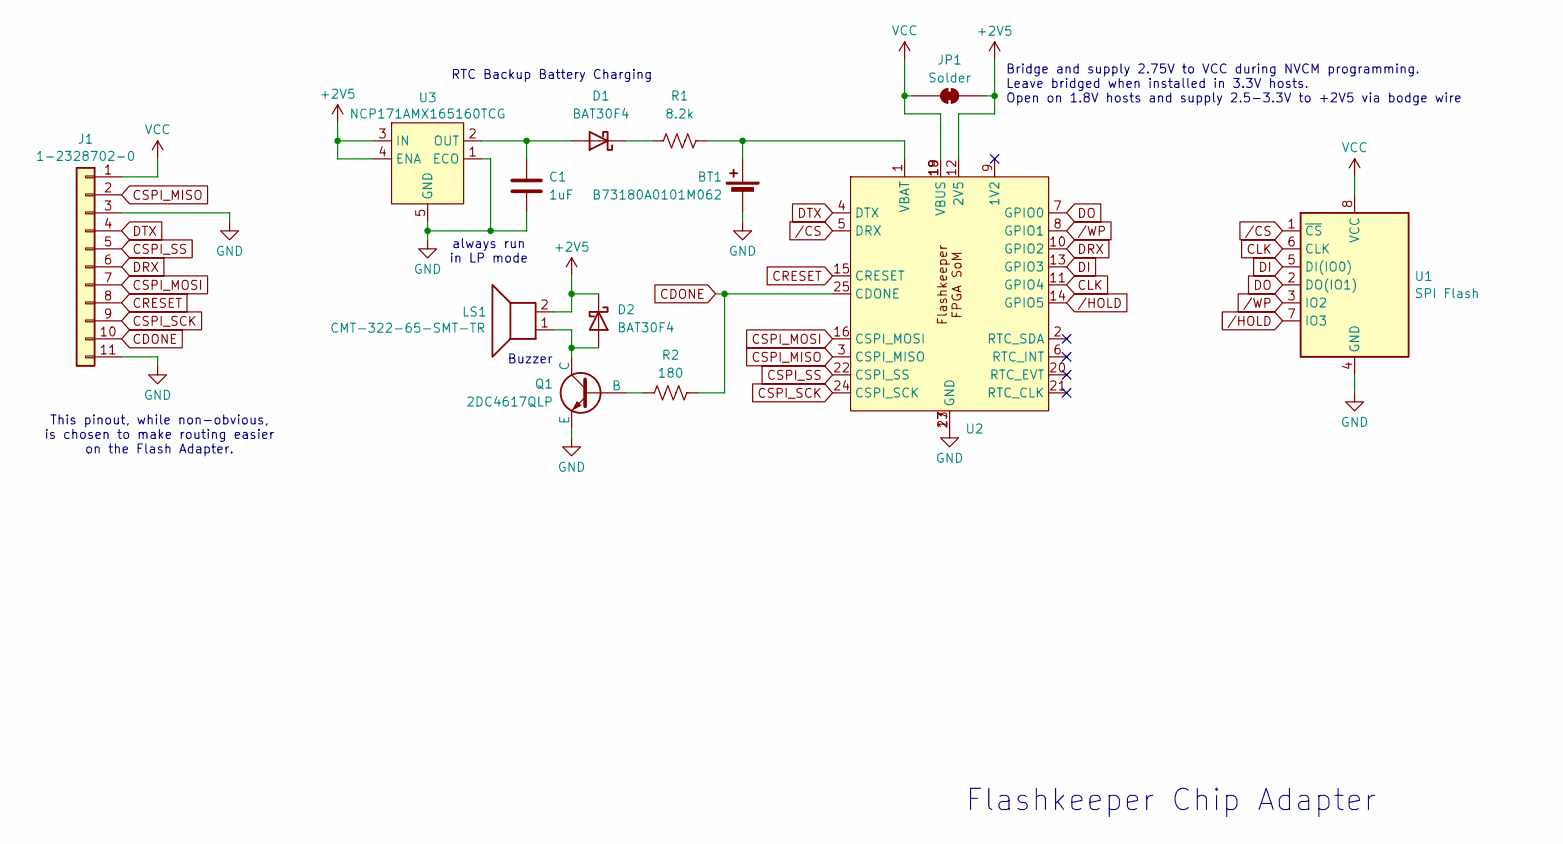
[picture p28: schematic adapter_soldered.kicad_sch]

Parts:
BT1: B73180A0101M062; C_1812_4532Metric
C1: 1uF; C_0201_0603Metric
D1, D2: BAT30F4; D_0201_0603Metric
J1: 1-2328702-0; TE_1-2328702-0
JP1: Solder; SolderJumper_0.4mm
LS1: CMT-322-65-SMT-TR; XDCR_CMT-322-65-SMT-TR
Q1: 2DC4617QLP; Diodes_DFN1006-3
R1: 8.2k; R_0201_0603Metric
R2: 180; R_0201_0603Metric
U1: SPI Flash; SolderConnector_SOIC8Wide_1.5mmLift
U2: FlashkeeperFPGASoM_ReducedPins
U3: NCP171AMX165160TCG; VREG_NCP171AMX180175TCG

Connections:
+2V5: D2.1 (K), JP1.2 (B), LS1.2, U2.12 (2V5), U3.3 (IN), U3.4 (ENA)
CDONE: J1.10, R2.2, U2.25 (CDONE)
CLK: U1.6 (CLK), U2.11 (GPIO4)
CRESET: J1.8, U2.15 (CRESET)
CSPI_MISO: J1.2, U2.3 (CSPI_MISO)
CSPI_MOSI: J1.7, U2.16 (CSPI_MOSI)
CSPI_SCK: J1.9, U2.24 (CSPI_SCK)
CSPI_SS: J1.5, U2.22 (CSPI_SS)
DI: U1.5 (DI(IO0)), U2.13 (GPIO3)
DO: U1.2 (DO(IO1)), U2.7 (GPIO0)
DRX: J1.6, U2.10 (GPIO2)
DTX: J1.4, U2.4 (DTX)
GND: BT1.2 (-), C1.2, J1.3, J1.11, Q1.3 (E), U1.4 (GND), U2.17 (GND), U2.23 (GND), U3.1 (ECO), U3.5 (GND)
unnamed: BT1.1 (+), R1.2, U2.1 (VBAT)
unnamed: C1.1, D1.2 (A), U3.2 (OUT)
unnamed: D1.1 (K), R1.1
unnamed: D2.2 (A), LS1.1, Q1.1 (C)
unnamed: Q1.2 (B), R2.1
VCC: J1.1, JP1.1 (A), U1.8 (VCC), U2.18 (VBUS), U2.19 (VBUS)
/CS: U1.1 (~CS), U2.5 (DRX)
/HOLD: U1.7 (IO3), U2.14 (GPIO5)
/WP: U1.3 (IO2), U2.8 (GPIO1)

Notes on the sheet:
RTC Backup Battery Charging
Flashkeeper Chip Adapter
always run in LP mode
Bridge and supply 2.75V to VCC during NVCM programming. Leave bridged when installed in 3.3V hosts. Open on 1.8V hosts and supply 2.5-3.3V to +2V5 via bodge wire
Buzzer
This pinout, while non-obvious, is chosen to make routing easier on the Flash Adapter.

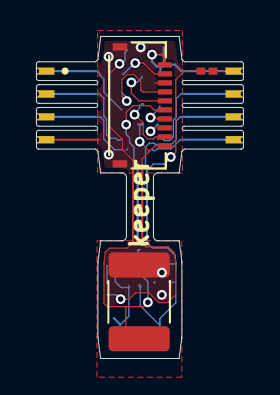
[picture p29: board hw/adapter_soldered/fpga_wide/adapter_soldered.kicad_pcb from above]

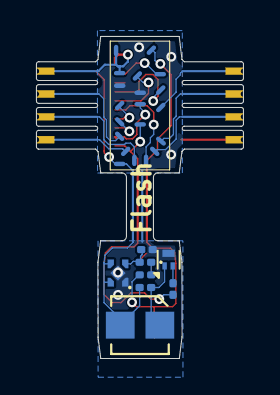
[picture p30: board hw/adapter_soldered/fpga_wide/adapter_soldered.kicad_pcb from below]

Board: 2 copper layers, 11.5 x 17.9 mm, 13 parts (9 on the bottom side), 22 nets.

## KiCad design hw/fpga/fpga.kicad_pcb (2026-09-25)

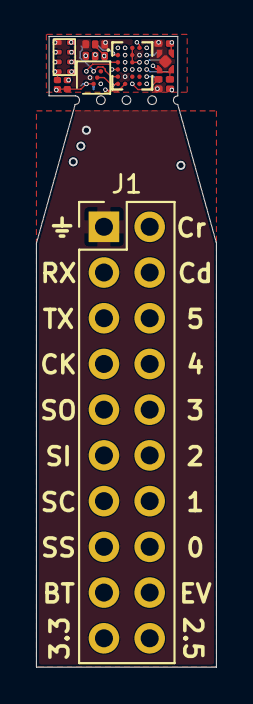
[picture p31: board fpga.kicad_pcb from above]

Board: 6 copper layers, 10.0 x 35.0 mm, 37 parts (0 on the bottom side), 24 nets.

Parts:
C1, C2, C3, C4: 4.7 uF; C_Smaller_0201
J1: Conn_02x09_Odd_Even; PinHeader_2x10_P2.54mm_Vertical
R1: 10k; R_Smaller_0201
R3: 100; R_Smaller_0201
RN1: 10k; YC102
TP1, TP2, TP3, TP4, TP5, TP6, TP7, TP8, TP9, TP10, TP11, TP12, TP13, TP14, TP15, TP16, TP17, TP18, TP19, TP20, TP21, TP23, TP24, TP25, TP26: FPGACenterPad
U1: ICE40UP5K-UWG30ITR; BGA30N40P5X6_253X211X60N
U2: TPS7A2012PDQNR; Texas_X2SON-4_1x1mm_P0.65mm
U3: AT25DF041B-UUN-T; WLCSP-8_1.58x1.63x0.35mm_Layout3x5_P0.35x0.4mm_Ball0.25mm_P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
U4: RV-3028-C8

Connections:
+1V2: C2.1, R3.1, TP20.1, U1.C2 (VCC), U2.1 (OUT)
+2V5: C4.2, J1.20, TP19.1, U1.D4 (VPP_2V5)
CDONE: J1.4, TP1.1, U1.D3 (IOB_12A/G4_~CDONE)
CLK: J1.7, TP11.1, U1.F2 (IOB_25B/G3), U4.1 (CLKOUT)
CRESET: J1.2, R1.2, TP18.1, U1.F3 (~CRESET_B)
CSPI_MISO: J1.11, TP13.1, U1.E1 (IOB_33B/SPI_SI), U3.C3 (SO/IO1)
CSPI_MOSI: J1.9, TP12.1, U1.F1 (IOB_32A/SPI_SO), U3.D2 (SI/IO0)
CSPI_SCK: J1.13, TP14.1, U1.D1 (IOB_34A/SPI_SCK), U3.E1 (SCK), U4.3 (SCL)
CSPI_SS: J1.15, RN1.4 (R2.2), TP15.1, U1.C1 (IOB_35B/SPI_SS_B), U3.A3 (~CS)
DRX: J1.3, TP10.1, U1.A1 (IOT_36B)
DTX: J1.5, TP17.1, U1.B1 (IOB_24A)
EVT: J1.18, RN1.2 (R1.2), TP23.1, U4.8 (EVI)
GND: C1.2, C2.2, C3.1, C4.1, J1.1, TP16.1, TP25.1, U1.B4 (GND), U1.E2 (GND), U2.2 (GND), U2.5 (Pad), U3.B2 (GND), U4.5 (VSS)
GPIO0: J1.16, TP2.1, U1.A5 (RGB0)
GPIO1: J1.14, TP3.1, U1.B5 (RGB1)
GPIO2: J1.12, TP4.1, U1.C5 (RGB2)
GPIO3: J1.10, TP5.1, U1.E5 (IOB_0A)
GPIO4: J1.8, TP6.1, U1.D5 (IOB_2A)
GPIO5: J1.6, TP7.1, U1.F5 (IOB_3B/G6)
unnamed: C1.1, R3.2, U1.B2 (VCCPLL)
RTC_INT: TP8.1, U1.A4 (IOT_47A), U4.2 (~INT)
RTC_SDA: TP24.1, U1.A2 (IOT_37A), U4.4 (SDA)
VBAT: J1.17, TP21.1, U4.6 (VBACKUP)
VBUS: C3.2, J1.19, R1.1, RN1.1 (R1.1), RN1.3 (R2.1), TP9.1, TP26.1, U1.A3 (VCCIO_0), U1.B3 (IOT_46B/G0), U1.C3 (IOB_10A), U1.C4 (VCCIO_2), U1.D2 (SPI_VCCIO1), U2.3 (EN), U2.4 (IN), U3.A1 (VCC), U3.C1 (~HOLD), U4.7 (VDD)

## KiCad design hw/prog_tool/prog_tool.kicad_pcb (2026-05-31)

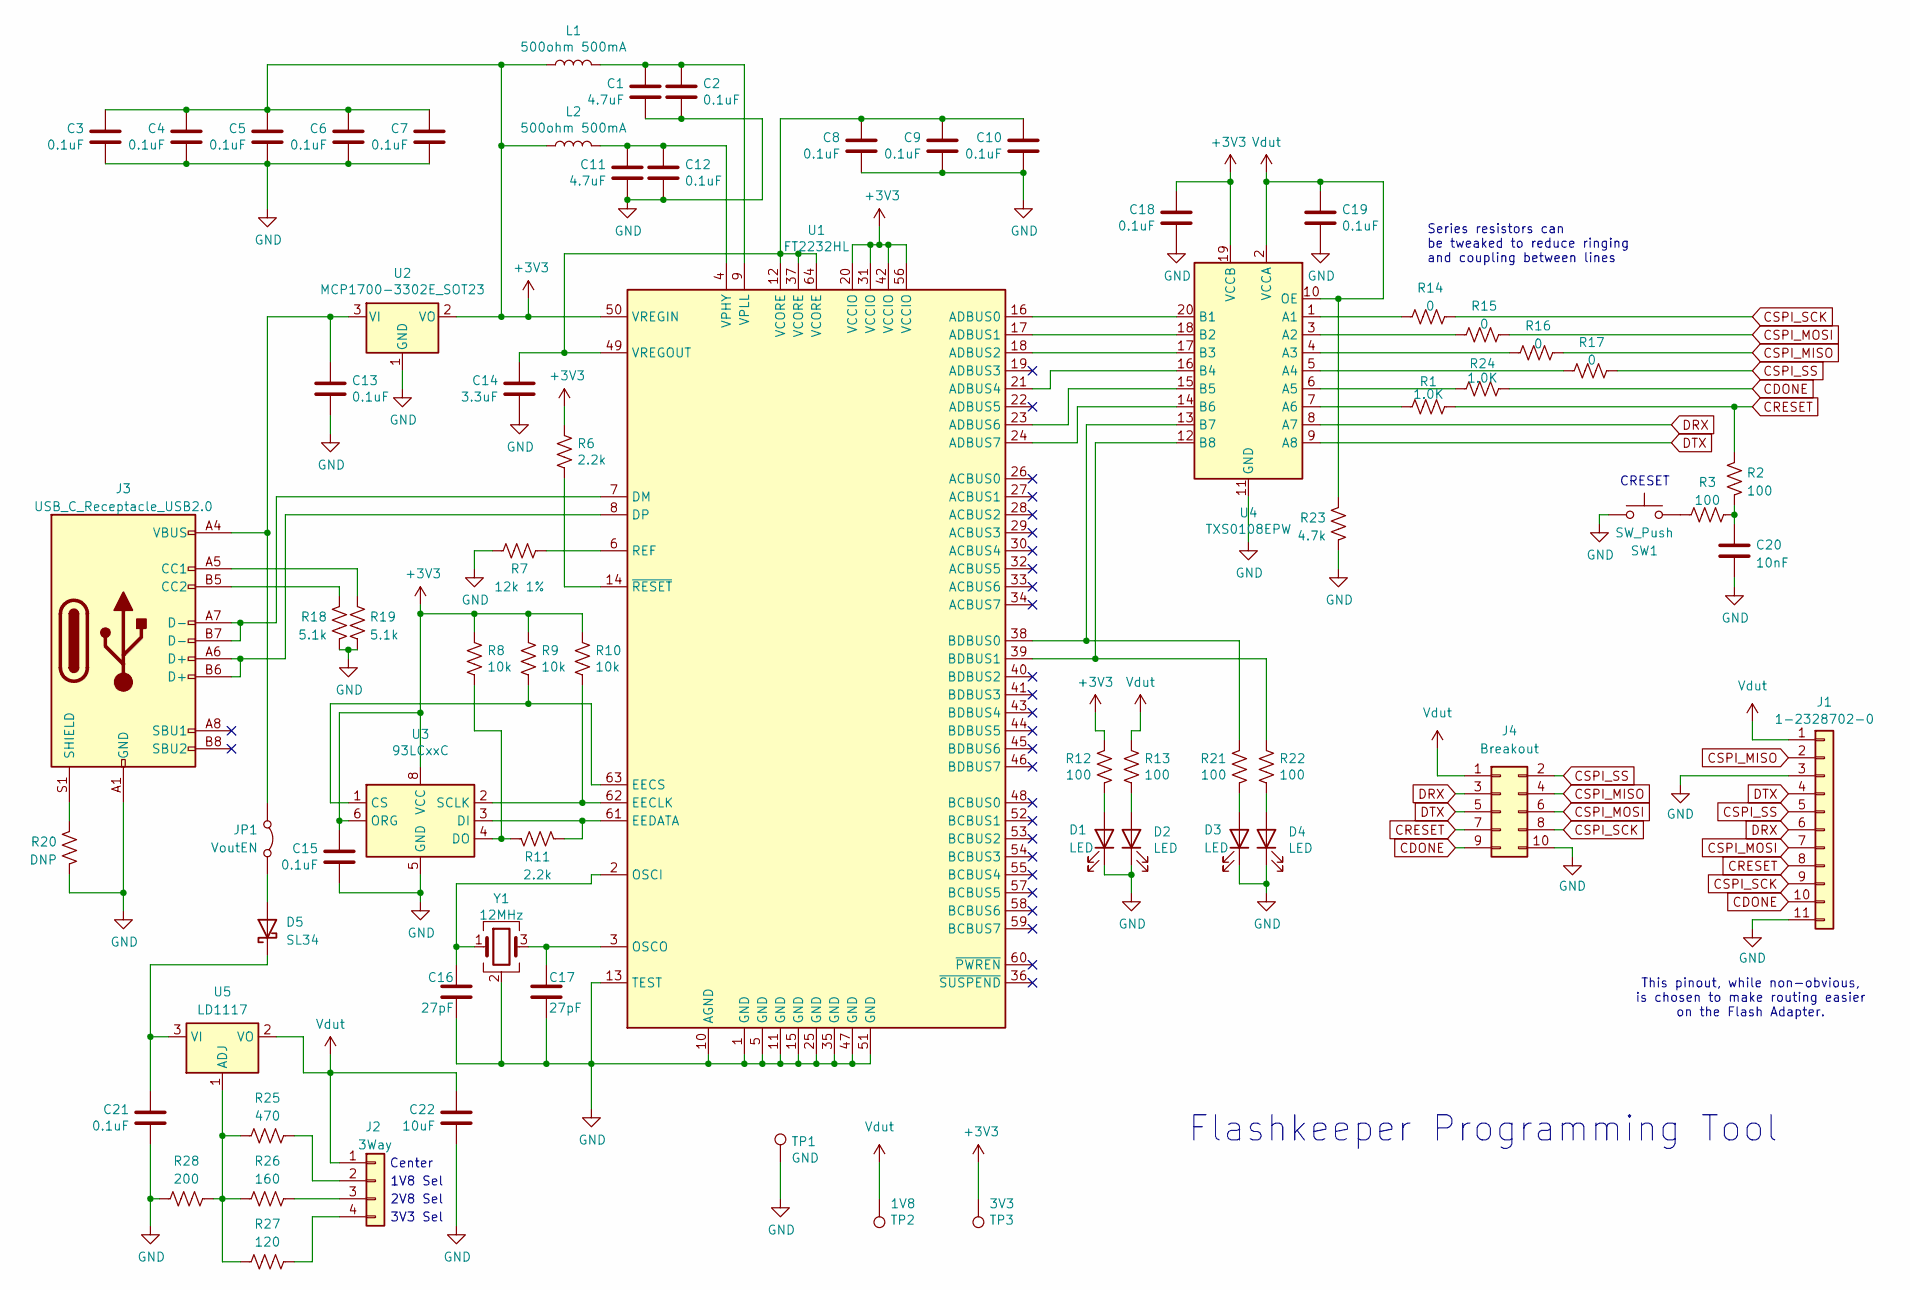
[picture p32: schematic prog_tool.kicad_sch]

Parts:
C1, C11: 4.7uF; C_0603_1608Metric
C2, C3, C4, C5, C6, C7, C8, C9, C10, C12, C13, C15, C18, C19, C21: 0.1uF; C_0603_1608Metric
C14: 3.3uF; C_0603_1608Metric
C16, C17: 27pF; C_0603_1608Metric
C20: 10nF; C_0603_1608Metric
C22: 10uF; C_0603_1608Metric
D1, D2, D3, D4: LED; LED_0603_1608Metric
D5: SL34; D_SMA
J1: 1-2328702-0; TE_1-2328702-0
J2: 3Way; ThreeWayJumper
J3: USB_C_Receptacle_USB2.0; USB4215-03-A
J4: Breakout; PinHeader_2x05_P2.54mm_Vertical
JP1: VoutEN; PinHeader_1x02_P2.54mm_Vertical
L1, L2: 500ohm 500mA; L_0603_1608Metric
R1, R24: 1.0K; R_0603_1608Metric
R2, R3, R12, R13, R21, R22: 100; R_0603_1608Metric
R6, R11: 2.2k; R_0603_1608Metric
R7: 12k 1%; R_0603_1608Metric
R8, R9, R10: 10k; R_0603_1608Metric
R14, R15, R16, R17: 0; R_0603_1608Metric
R18, R19: 5.1k; R_0603_1608Metric
R20: DNP; R_0603_1608Metric
R23: 4.7k; R_0603_1608Metric
R25: 470; R_0603_1608Metric
R26: 160; R_0603_1608Metric
R27: 120; R_0603_1608Metric
R28: 200; R_0603_1608Metric
SW1: SW_Push; SW_PUSH_6mm
TP1: GND; TestPoint_THTPad_2.0x2.0mm_Drill1.0mm
TP2: 1V8; TestPoint_THTPad_2.0x2.0mm_Drill1.0mm
TP3: 3V3; TestPoint_THTPad_2.0x2.0mm_Drill1.0mm
U1: FT2232HL; LQFP-64_10x10mm_P0.5mm
U2: MCP1700-3302E_SOT23; SOT-23
U3: 93LCxxC; SOIC-8_3.9x4.9mm_P1.27mm
U4: TXS0108EPW; TSSOP-20_4.4x6.5mm_P0.65mm
U5: LD1117; SOT-223-3_TabPin2
Y1: 12MHz; Crystal_SMD_3225-4Pin_3.2x2.5mm

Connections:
+3V3: C3.2, C4.2, C5.2, C6.2, C7.2, C15.2, C18.2, L1.1, L2.1, R6.1, R8.1, R9.1, R10.1, R12.2, TP3.1 (1_1), U1.20 (VCCIO), U1.31 (VCCIO), U1.42 (VCCIO), U1.50 (VREGIN), U1.56 (VCCIO), U2.2 (VO), U3.6 (ORG), U3.8 (VCC), U4.19 (VCCB)
CDONE: J1.10, J4.9, R24.2
CRESET: J1.8, J4.7, R1.2, R2.1
CSPI_MISO: J1.2, J4.4, R16.1
CSPI_MOSI: J1.7, J4.6, R15.1
CSPI_SCK: J1.9, J4.8, R14.1
CSPI_SS: J1.5, J4.2, R17.1
DRX: J1.6, J4.3, U4.8 (A7)
DTX: J1.4, J4.5, U4.9 (A8)
GND: C1.1, C2.2, C3.1, C4.1, C5.1, C6.1, C7.1, C8.1, C9.1, C10.1, C11.1, C12.2, C13.2, C14.1, C15.1, C16.1, C17.1, C18.1, C19.2, C20.2, C21.1, C22.1, D1.1 (K), D2.1 (K), D3.1 (K), D4.1 (K), J1.3, J1.11, J3.A1 (GND), J3.A12 (GND), J3.B1 (GND), J3.B12 (GND), J4.10, R7.2, R18.1, R19.2, R20.1, R23.1, R28.1, SW1.2, TP1.1 (1_1), U1.1 (GND), U1.5 (GND), U1.10 (AGND), U1.11 (GND), U1.13 (TEST), U1.15 (GND), U1.25 (GND), U1.35 (GND), U1.47 (GND), U1.51 (GND), U2.1 (GND), U3.5 (GND), U4.11 (GND), Y1.2 (G), Y1.4 (G)
unnamed: C20.1, R2.2, R3.2
unnamed: D1.2 (A), R12.1
unnamed: D2.2 (A), R13.2
unnamed: D3.2 (A), R21.1
unnamed: D4.2 (A), R22.2
unnamed: D5.2 (A), JP1.1 (A)
unnamed: C21.2, D5.1 (K), U5.3 (VI)
unnamed: J2.2, R25.2
unnamed: J2.3, R26.2
unnamed: J2.4, R27.2
unnamed: J3.A5 (CC1), R19.1
unnamed: J3.B5 (CC2), R18.2
unnamed: J3.S1 (SHIELD), R20.2
unnamed: C13.1, J3.A4 (VBUS), J3.A9 (VBUS), J3.B4 (VBUS), J3.B9 (VBUS), JP1.2 (B), U2.3 (VI)
unnamed: R3.1, SW1.1
unnamed: U1.16 (ADBUS0), U4.20 (B1)
unnamed: U1.17 (ADBUS1), U4.18 (B2)
unnamed: U1.18 (ADBUS2), U4.17 (B3)
unnamed: U1.21 (ADBUS4), U4.16 (B4)
unnamed: U1.23 (ADBUS6), U4.15 (B5)
unnamed: U1.24 (ADBUS7), U4.14 (B6)
unnamed: R21.2, U1.38 (BDBUS0), U4.13 (B7)
unnamed: R22.1, U1.39 (BDBUS1), U4.12 (B8)
unnamed: J3.A7 (D-), J3.B7 (D-), U1.7 (DM)
unnamed: J3.A6 (D+), J3.B6 (D+), U1.8 (DP)
unnamed: R10.2, U1.62 (EECLK), U3.2 (SCLK)
unnamed: R9.2, U1.63 (EECS), U3.1 (CS)
unnamed: R11.2, U1.61 (EEDATA), U3.3 (DI)
unnamed: C16.2, U1.2 (OSCI), Y1.1
unnamed: C17.2, U1.3 (OSCO), Y1.3
unnamed: R7.1, U1.6 (REF)
unnamed: C11.2, C12.1, L2.2, U1.4 (VPHY)
unnamed: C1.2, C2.1, L1.2, U1.9 (VPLL)
unnamed: C8.2, C9.2, C10.2, C14.2, U1.12 (VCORE), U1.37 (VCORE), U1.49 (VREGOUT), U1.64 (VCORE)
unnamed: R6.2, U1.14 (~RESET)
unnamed: R8.2, R11.1, U3.4 (DO)
unnamed: R14.2, U4.1 (A1)
unnamed: R15.2, U4.3 (A2)
unnamed: R16.2, U4.4 (A3)
unnamed: R17.2, U4.5 (A4)
unnamed: R24.1, U4.6 (A5)
unnamed: R1.1, U4.7 (A6)
unnamed: R25.1, R26.1, R27.1, R28.2, U5.1 (ADJ)
Vdut: C19.1, C22.2, J1.1, J2.1, J4.1, R13.1, R23.2, TP2.1 (1_1), U4.2 (VCCA), U4.10 (OE), U5.2 (VO)

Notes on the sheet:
1V8 Sel
Center
This pinout, while non-obvious, is chosen to make routing easier on the Flash Adapter.
3V3 Sel
Flashkeeper Programming Tool
2V8 Sel
CRESET
Series resistors can be tweaked to reduce ringing and coupling between lines

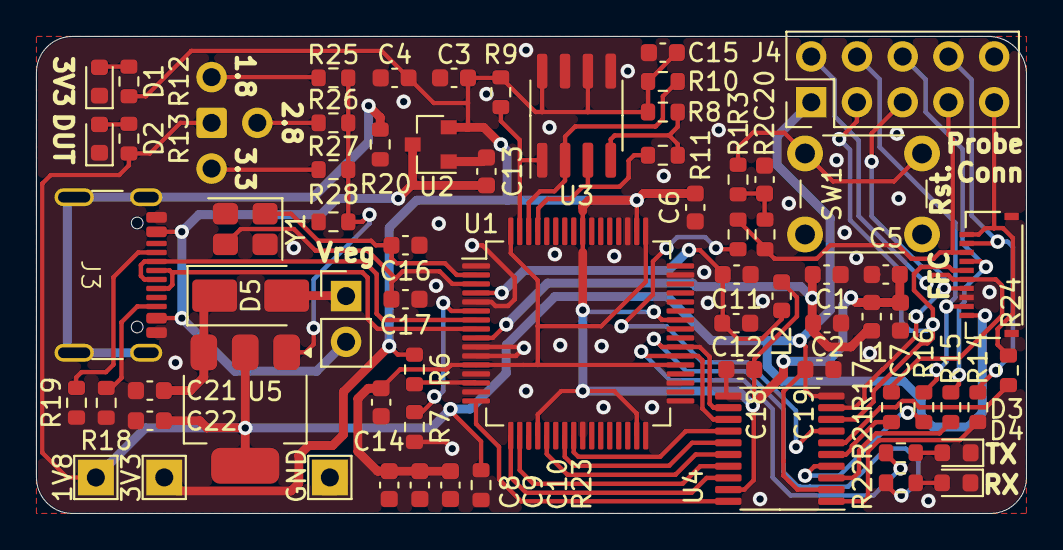
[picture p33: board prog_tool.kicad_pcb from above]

Board: 2 copper layers, 55.0 x 26.5 mm, 70 parts (0 on the bottom side), 54 nets.

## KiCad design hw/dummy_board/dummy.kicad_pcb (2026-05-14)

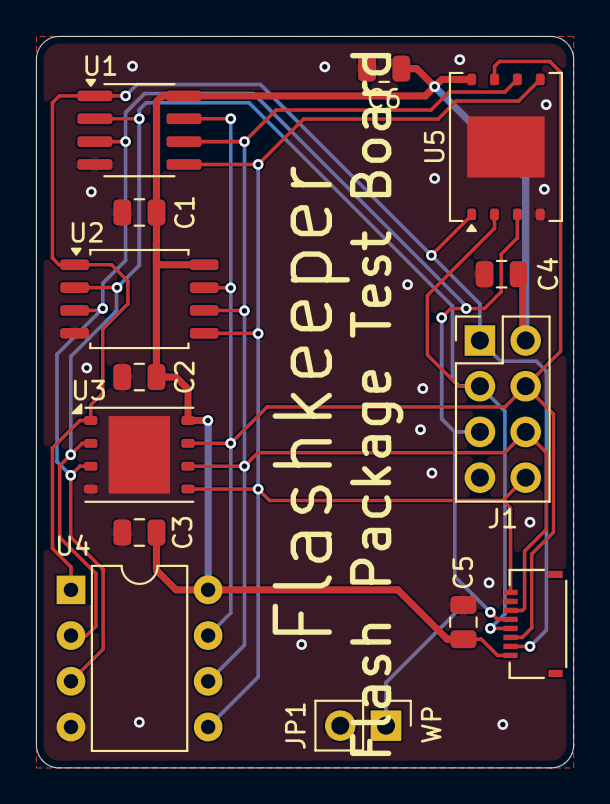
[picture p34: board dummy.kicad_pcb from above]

Board: 2 copper layers, 29.8 x 40.6 mm, 14 parts (0 on the bottom side), 8 nets.

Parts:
C1, C2, C3, C4, C5, C6: 0.1uF; C_0805_2012Metric
J1: Conn_02x04; PinHeader_2x04_P2.54mm_Vertical
J2: FFC; TE_2328702-8
JP1: Jumper_2_Open; PinHeader_1x02_P2.54mm_Vertical
U1: W25Q128JVS; SOIC-8_3.9x4.9mm_P1.27mm
U2: W25Q128JVS; SOIC-8_5.23x5.23mm_P1.27mm
U3: W25Q128JVP; WSON-8-1EP_6x5mm_P1.27mm_EP3.4x4.3mm
U4: W25Q128JVS; DIP-8_W7.62mm
U5: W25Q128JVP; WSON-8-1EP_8x6mm_P1.27mm_EP3.4x4.3mm

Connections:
CLK: J1.6, J2.6, U1.6 (CLK), U2.6 (CLK), U3.6 (CLK), U4.6 (CLK), U5.6 (CLK)
CS: J1.1, J2.2, U1.1 (~CS), U2.1 (~CS), U3.1 (~CS), U4.1 (~CS), U5.1 (~CS)
DI: J1.8, J2.8, U1.5 (DI(IO0)), U2.5 (DI(IO0)), U3.5 (DI(IO0)), U4.5 (DI(IO0)), U5.5 (DI(IO0))
DO: J1.3, J2.4, U1.2 (DO(IO1)), U2.2 (DO(IO1)), U3.2 (DO(IO1)), U4.2 (DO(IO1)), U5.2 (DO(IO1))
GND: C1.2, C2.2, C3.2, C4.2, C5.2, C6.2, J1.7, J2.7, JP1.2 (B), U1.4 (GND), U2.4 (GND), U3.4 (GND), U3.9 (GND), U4.4 (GND), U5.4 (GND), U5.9 (GND)
IO2: J1.5, J2.5, JP1.1 (A), U1.3 (IO2), U2.3 (IO2), U3.3 (IO2), U4.3 (IO2), U5.3 (IO2)
IO3: J1.4, J2.3, U1.7 (IO3), U2.7 (IO3), U3.7 (IO3), U4.7 (IO3), U5.7 (IO3)
VCC: C1.1, C2.1, C3.1, C4.1, C5.1, C6.1, J1.2, J2.1, U1.8 (VCC), U2.8 (VCC), U3.8 (VCC), U4.8 (VCC), U5.8 (VCC)

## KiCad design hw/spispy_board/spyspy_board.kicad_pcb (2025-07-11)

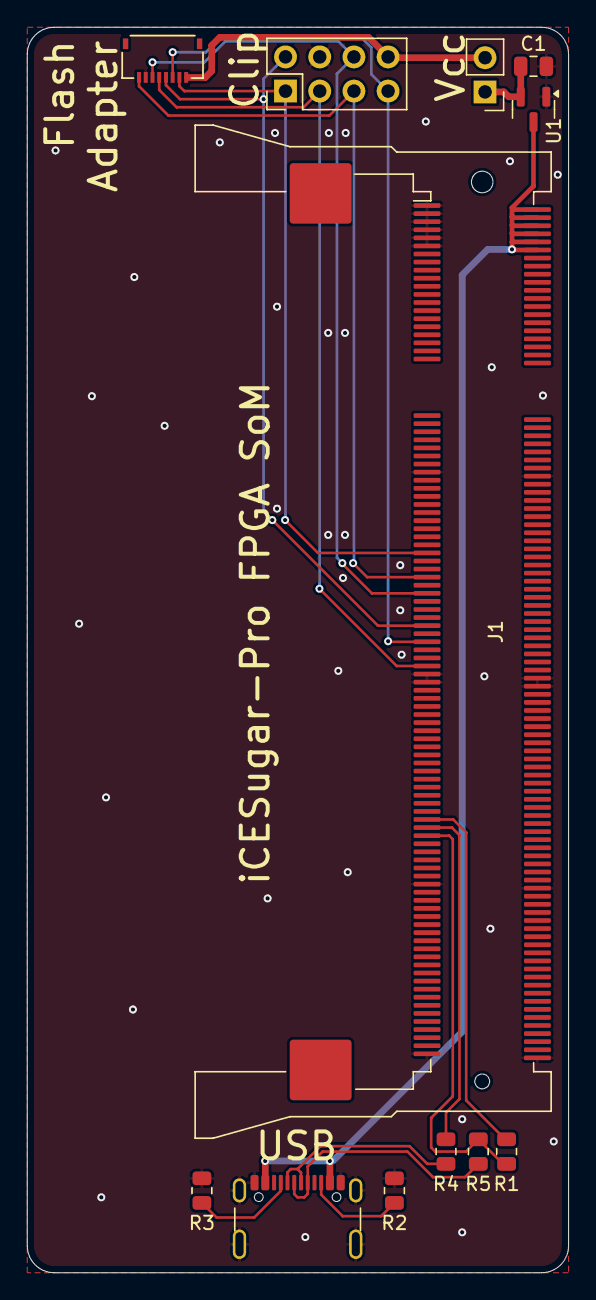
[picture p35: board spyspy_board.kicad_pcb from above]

Board: 2 copper layers, 40.2 x 92.5 mm, 12 parts (0 on the bottom side), 17 nets.

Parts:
C1: 0.1uF; C_0805_2012Metric
J1: SODIMM-200; TE_DDR2-SODIMM-200_1565918-4
J2: USB_C_Receptacle_USB2.0_16P; USB4215-03-A
J3: Header_2x4; PinHeader_2x04_P2.54mm_Vertical
J4: FFC; TE_2328702-8
JP1: Jumper_2_Bridged; PinHeader_1x02_P2.54mm_Vertical
R1: 1.5k; R_0805_2012Metric
R2, R3: 5.1k; R_0805_2012Metric
R4, R5: 27; R_0805_2012Metric
U1: MCP1700x-330xxTT; SOT-23

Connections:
+3V3: C1.1, JP1.1 (A), U1.2 (VO)
+5V: J1.2, J1.4, J1.6, J1.8, J1.10, J1.12, J2.A4 (VBUS), J2.A9 (VBUS), J2.B4 (VBUS), J2.B9 (VBUS), U1.3 (VI)
CLK: J1.85, J3.6, J4.6
DI: J1.81, J3.5, J4.8
DO: J1.93, J3.2, J4.4
FPGA_D+: J1.145, R1.2, R5.1
FPGA_D+_PULL: J1.141, R1.1
FPGA_D-: J1.143, R4.1
GND: C1.2, J1.1, J1.3, J1.5, J1.7, J1.9, J1.11, J1.55, J1.56, J1.105, J1.106, J1.107, J1.108, J1.157, J1.158, J1.199, J1.200, J2.A1 (GND), J2.A12 (GND), J2.B1 (GND), J2.B12 (GND), J2.S1 (SHIELD), J3.4, J4.7, R2.2, R3.2, U1.1 (GND)
unnamed: J2.A5 (CC1), R3.1
unnamed: J2.B5 (CC2), R2.1
unnamed: J2.A6 (D+), J2.B6 (D+), R5.2
unnamed: J2.A7 (D-), J2.B7 (D-), R4.2
unnamed: J3.8, J4.1, JP1.2 (B)
/CS: J1.75, J3.1, J4.2
/HOLD: J1.97, J3.7, J4.3
/WP: J1.103, J3.3, J4.5

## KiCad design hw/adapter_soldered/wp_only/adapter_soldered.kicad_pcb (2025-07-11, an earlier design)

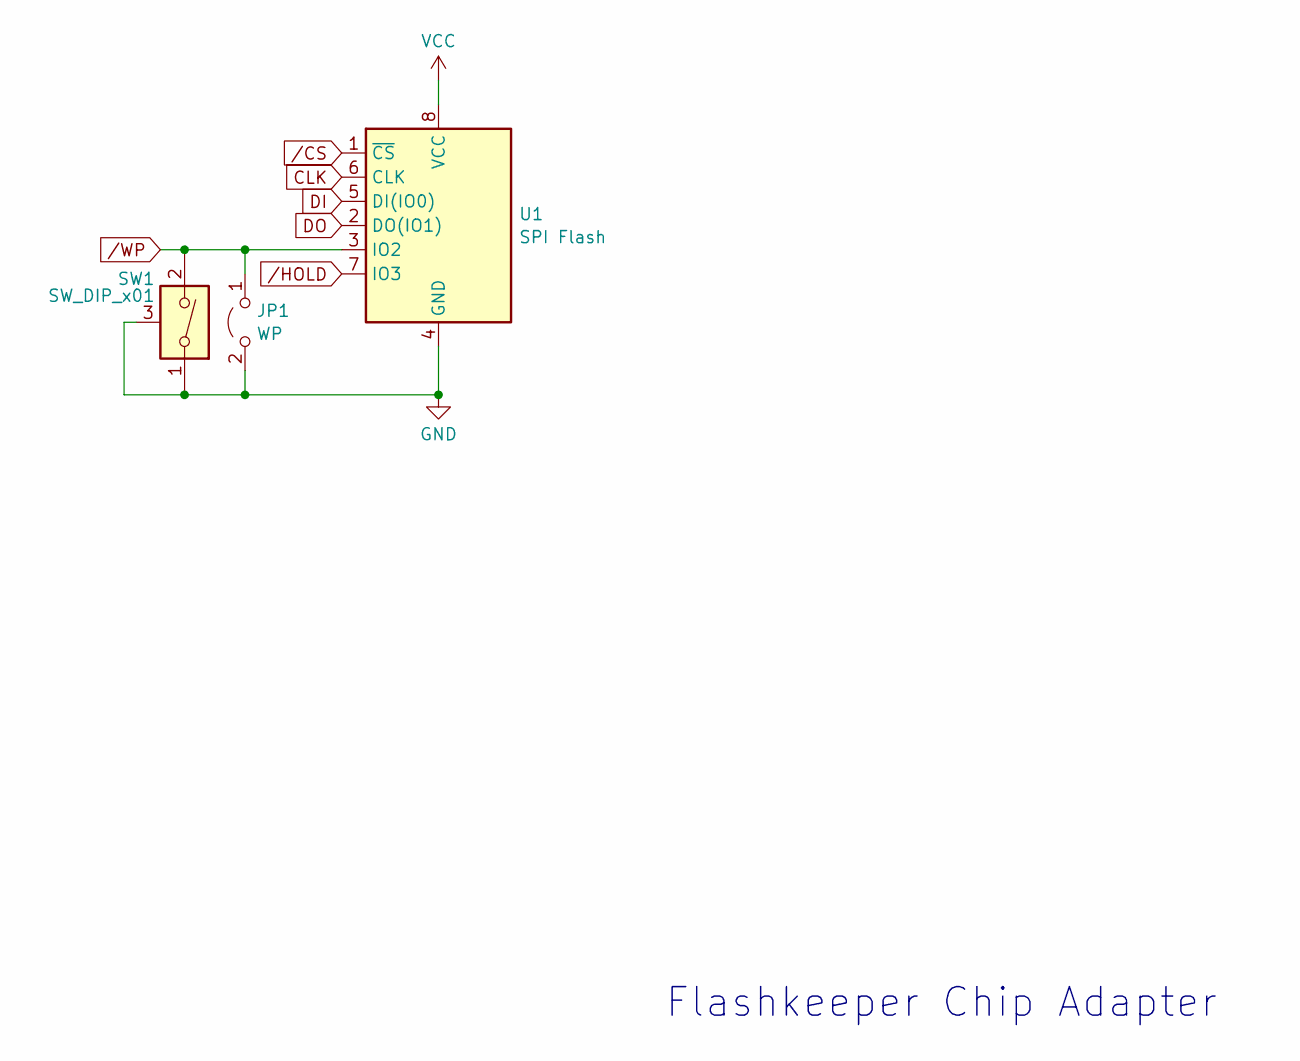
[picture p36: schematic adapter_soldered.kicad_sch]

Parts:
JP1: WP; SolderJumper-2_P1.3mm_Open_RoundedPad1.0x1.5mm
SW1: SW_DIP_x01; SW_DIP_SPSTx01_Slide_Copal_CVS-01xB_W5.9mm_P1mm
U1: SPI Flash; SolderConnector_SOIC8

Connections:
CLK: U1.6 (CLK)
DI: U1.5 (DI(IO0))
DO: U1.2 (DO(IO1))
GND: JP1.2 (B), SW1.1, SW1.3 (GND), U1.4 (GND)
VCC: U1.8 (VCC)
/CS: U1.1 (~CS)
/HOLD: U1.7 (IO3)
/WP: JP1.1 (A), SW1.2, U1.3 (IO2)

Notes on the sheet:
Flashkeeper Chip Adapter

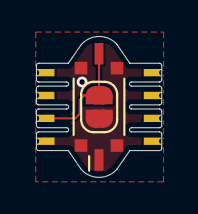
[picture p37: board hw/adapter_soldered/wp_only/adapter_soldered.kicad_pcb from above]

Board: 2 copper layers, 7.0 x 7.8 mm, 3 parts (0 on the bottom side), 2 nets.

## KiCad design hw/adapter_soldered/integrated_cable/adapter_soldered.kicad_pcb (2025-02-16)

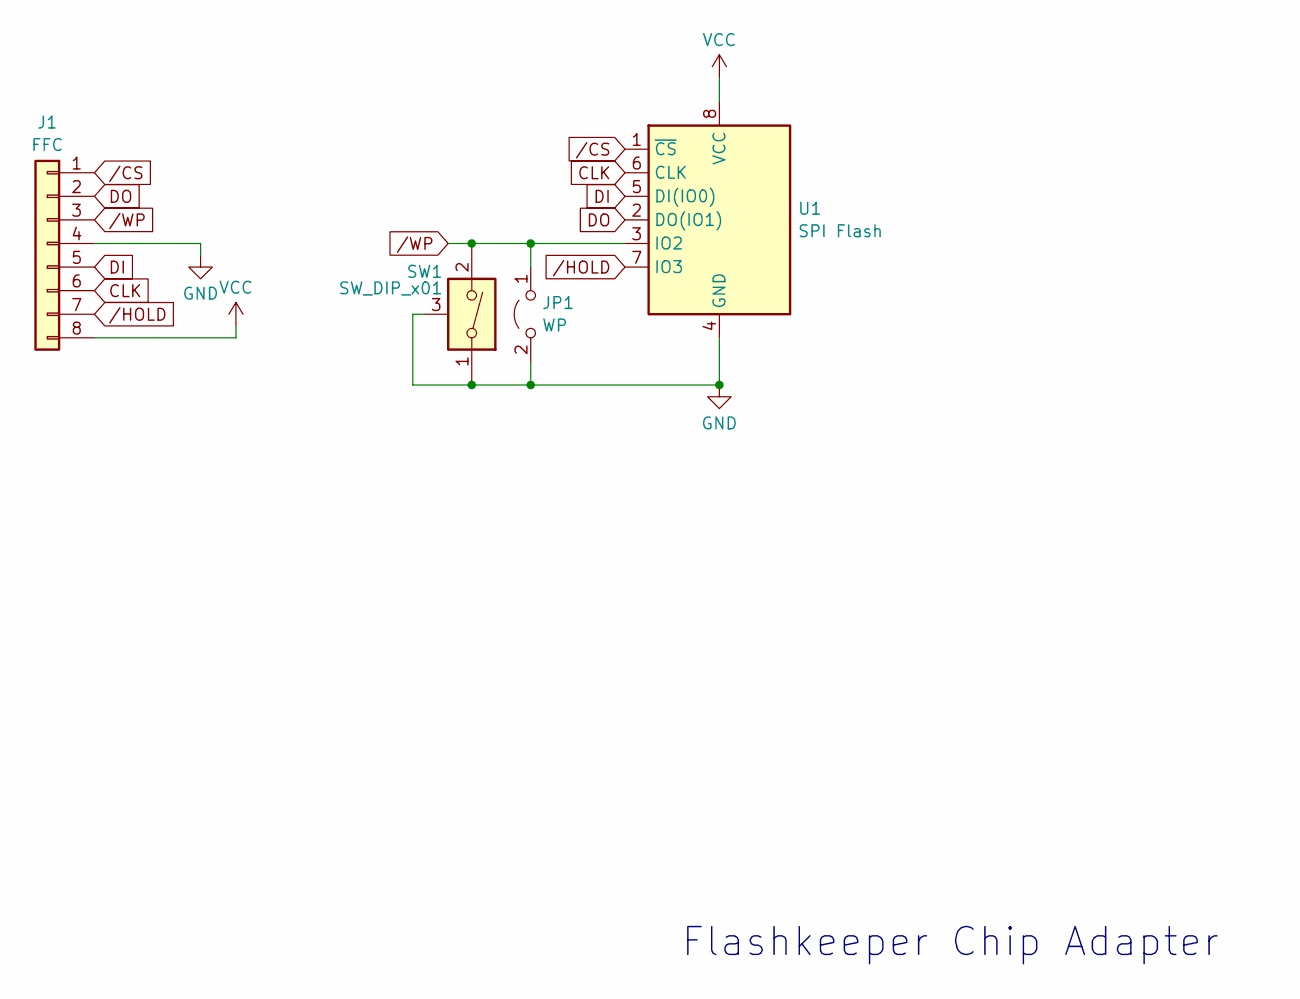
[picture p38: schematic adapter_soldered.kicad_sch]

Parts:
J1: FFC; FFC_8_0.5mm
JP1: WP; SolderJumper-2_P1.3mm_Open_RoundedPad1.0x1.5mm
SW1: SW_DIP_x01; SW_DIP_SPSTx01_Slide_Copal_CVS-01xB_W5.9mm_P1mm
U1: SPI Flash; SolderConnector_SOIC8

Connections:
CLK: J1.6, U1.6 (CLK)
DI: J1.5, U1.5 (DI(IO0))
DO: J1.2, U1.2 (DO(IO1))
GND: J1.4, JP1.2 (B), SW1.1, SW1.3 (GND), U1.4 (GND)
VCC: J1.8, U1.8 (VCC)
/CS: J1.1, U1.1 (~CS)
/HOLD: J1.7, U1.7 (IO3)
/WP: J1.3, JP1.1 (A), SW1.2, U1.3 (IO2)

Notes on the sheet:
Flashkeeper Chip Adapter

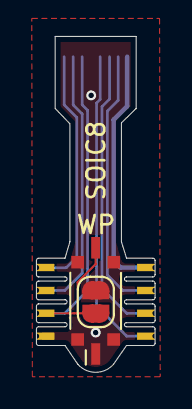
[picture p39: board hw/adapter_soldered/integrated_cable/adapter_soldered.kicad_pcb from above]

Board: 2 copper layers, 6.6 x 18.7 mm, 4 parts (0 on the bottom side), 8 nets.

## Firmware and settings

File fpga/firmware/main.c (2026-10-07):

#include "picosoc.h"
#include "serprog.h"
#include <stdint.h>
#include "memops.h"
#include "romapi.h" /* SHA-512 in the ROM (fk_rom_hash_*); via romcalls.s */
#include "tweetnacl.h" /* local tweetnacl functions (crypto_verify_64) */
#include "rng.h"

#define _EDE_IMPLEMENTATION_
#include "ede.h"

#include "flashkeeper_config.h"

#define SERIAL_PASSWORD_SALT_BYTES 16

extern void randombytes(uint8_t *, uint64_t);

void hspi_read_flash_id(){
	uint8_t buffer[4] = { 0x9F, };
	hspi_flashio(buffer, 4, 0);

	for (int i = 1; i <= 3; i++) {
		putchar(' ');
		print_hex(buffer[i], 2);
	}
	putchar('\n');
}

void hspi_print_spi_state(){
	print("SPI State:\n");

	print("  LATENCY ");
	print_dec((reg_hspictrl >> 16) & 15);
	print("\n");

	print("  DDR ");
	if ((reg_hspictrl & (1 << 22)) != 0)
		print("ON\n");
	else
		print("OFF\n");

	print("  QSPI ");
	if ((reg_hspictrl & (1 << 21)) != 0)
		print("ON\n");
	else
		print("OFF\n");

	print("  CRM ");
	if ((reg_hspictrl & (1 << 20)) != 0)
		print("ON\n");
	else
		print("OFF\n");
}

// (value -- )
void config_spi(edei32 *s, edeu16 *sp, volatile uint32_t* reg){
    if(*sp < 1){
        print("Must provide parameters\n");
        return;
    }
    *reg = (uint32_t) s[*sp - 1];
    *sp = *sp - 1;
}

void config_hspi(edei32 *s, edeu16 *sp){
    config_spi(s, sp, &reg_hspictrl);
}

void config_cspi(edei32 *s, edeu16 *sp){
    config_spi(s, sp, &reg_cspictrl);
}

// (addr len -- )
void dump_mem(edei32 *s, edeu16 *sp, volatile uint8_t* base, uint32_t window_size){
    if(*sp < 2){
        print("Must provide parameters\n");
        return;
    }
    uint32_t addr = (uint32_t) s[*sp - 2];
    uint32_t len  = (uint32_t) s[*sp - 1];
    *sp = *sp - 2;
    // Reading past the end of the memory-mapped window hits unmapped space
    // and hangs the core, so bound-check before touching `base`.
    if(addr >= window_size || len > window_size - addr){
        print("Out of window\n");
        return;
    }
    for (uint32_t i = addr; i < addr + len; i++) {
        putchar(' ');
        print_hex(base[i], 2);
    }
    putchar('\n');
}

void dump_hspi(edei32 *s, edeu16 *sp){
    // The window only works in MEMIO mode; manual mode is sticky after
    // any flashio worker call, so enable it explicitly here.
    spi_memio_enable(HSPI_CTL_ADDR);
    dump_mem(s, sp, (volatile uint8_t*) HSPI_BASE_ADDR, FLASH_WINDOW_SIZE);
}

void dump_cspi(edei32 *s, edeu16 *sp){
    spi_memio_enable(CSPI_CTL_ADDR);
    dump_mem(s, sp, (volatile uint8_t*) CSPI_BASE_ADDR, FLASH_WINDOW_SIZE);
}

void dump_brom(edei32 *s, edeu16 *sp){
    dump_mem(s, sp, (volatile uint8_t*) BROM_BASE_ADDR, BROM_WINDOW_SIZE);
}

uint8_t spi_sr(uint8_t reg, uint32_t reg_addr){
    uint8_t buffer[2] = {0};
    
    switch(reg){
        case 1: buffer[0] = 0x05; break; // Read Status Register-1
        case 2: buffer[0] = 0x35; break; // Read Status Register-2
        case 3: buffer[0] = 0x15; break; // Read Status Register-3
    }

    flashio_call(buffer, 2, 0, reg_addr, 0);

    return buffer[1];
}

void spi_print_sr(uint32_t reg_addr){
    print("SR1: ");
    print_hex(spi_sr(1, reg_addr), 2);
    print("\nSR2: ");
    print_hex(spi_sr(2, reg_addr), 2);
    print("\nSR3: ");
    print_hex(spi_sr(3, reg_addr), 2);
    print("\n");
}

void hspi_print_sr(){
    spi_print_sr(HSPI_CTL_ADDR);
}

void cspi_print_sr(){
    spi_print_sr(CSPI_CTL_ADDR);
}

void spi_wait_busy(uint32_t reg_addr){
    while(spi_sr(1, reg_addr) & 1); // loop until BUSY goes zero
}

void hspi_chip_erase(){
    uint8_t buffer[1] = {SPI_CMD_CHIP_ERASE};

    hspi_flashio(buffer, 1, SPI_CMD_WE);
    spi_wait_busy(HSPI_CTL_ADDR);
}

// ( d0 ... dn addr len -- )
void write_spi(edei32 *s, edeu16 *sp, uint32_t reg_addr){
    uint32_t flash_addr; // address to write at
    uint16_t len; // length of the write in bytes (1-256)
    uint8_t cells;

    if(*sp < 2){
        print("Must provide parameters\n");
        return;
    }

    flash_addr = s[*sp - 2] & 0x00FFFFFF;
    len = (uint16_t) s[*sp - 1];
    cells = (uint8_t)((len + 3) / 4);

    *sp = *sp - 2;

    if(len < 1){
        print("Length must be positive\n");
        return;
    }
    if((0x100 - (flash_addr & 0xFF)) < len){
        print("Write must fit within page\n");
        return;
    }
    if(cells > *sp){
        print("Insufficient data present on stack.\n");
        return;
    }
    uint32_t cmd = ((uint32_t) SPI_CMD_PP << 24) | flash_addr; // assemble a 32-bit write command (02h + 24-bit address)

    // Call flashio_call directly to use the prebuffer
    flashio_call((uint8_t*) (s + (*sp - cells)), len, SPI_CMD_WE, reg_addr, cmd);

    spi_wait_busy(reg_addr);

    *sp = *sp - cells;
}

void write_hspi(edei32 *s, edeu16 *sp){
    write_spi(s, sp, HSPI_CTL_ADDR);
}

void write_cspi(edei32 *s, edeu16 *sp){
    write_spi(s, sp, CSPI_CTL_ADDR);
}

void cmd_rng(edei32 *s, edeu16 *sp){
    if(*sp < 1){
        print("Must provide parameters\n");
        return;
    }
    int count = s[*sp - 1];
    if (count < 0 || count > 256) count = 256;

    static uint8_t buf[256];
    randombytes(buf, (size_t) count);
    for (int i = 0; i < count; i++) {
        putchar(' ');
        print_hex(buf[i], 2);
    }
    putchar('\n');

    rng_stats_t st;
    rng_get_stats(&st);

    print("rng: bits ");
    print_dec((int32_t) st.bits_seen);
    print(" ok ");
    print_dec((int32_t) st.batches_ok);
    print(" fail ");
    print_dec((int32_t) st.batches_fail);
    print(" rct_max ");
    print_dec((int32_t) st.rct_max);
    print(" apt_max ");
    print_dec((int32_t) st.apt_max);
    putchar('\n');

    *sp = *sp - 1;
}

// UART RX framing-error counter (uart status register bits [15:8]).
// Nonzero after a serprog session means the RX dropped bit-slipped frames;
// serprog NAKs any SPIOP whose window saw an increase.
void cmd_ferr(){
    print("uart ferr: ");
    print_dec((reg_uart_sts >> 8) & 0xFF);
    putchar('\n');
}

// Generate a password configuration for flashkeeper_config.h
void generate_password(){
    uint8_t hash_buffer[64];
    uint8_t password_buffer[65 + SERIAL_PASSWORD_SALT_BYTES]; // +1 for the NUL that ede_getstring_placeholder writes at offset maxlen
    uint16_t entered_len;

    // Initialize the password buffer with the salt
    randombytes(password_buffer, SERIAL_PASSWORD_SALT_BYTES);

    print("New Password: ");
    entered_len = ede_getstring_placeholder(getchar, putchar_raw, password_buffer + SERIAL_PASSWORD_SALT_BYTES, 64, '*');
    fk_rom_hash_sha512(hash_buffer, password_buffer, entered_len + SERIAL_PASSWORD_SALT_BYTES);

    print("static const uint32_t serial_password_salt[] = {");
    for(int i=0; i < SERIAL_PASSWORD_SALT_BYTES; i+=4){
        uint32_t w = (uint32_t) password_buffer[i] | ((uint32_t) password_buffer[i + 1] << 8) | ((uint32_t) password_buffer[i + 2] << 16) | ((uint32_t) password_buffer[i + 3] << 24);
        print("0x");
        ede_puthex(putchar, w, 32);
        if(i < SERIAL_PASSWORD_SALT_BYTES - 4) print(",");
    }
    print("};\n");

    print("static const uint32_t serial_password_hash[] = {");
    for(int i=0; i < 64; i += 4){
        uint32_t w = (uint32_t) hash_buffer[i] | ((uint32_t) hash_buffer[i + 1] << 8) | ((uint32_t) hash_buffer[i + 2] << 16) | ((uint32_t) hash_buffer[i + 3] << 24);
        print("0x");
        ede_puthex(putchar, w, 32);
        if(i < 60) print(",");
    }
    print("};\n");
}

void password_prompt(){
    uint8_t hash_buffer[64];
    uint8_t password_buffer[65 + SERIAL_PASSWORD_SALT_BYTES]; // +1 for the NUL that ede_getstring_placeholder writes at offset maxlen
    uint16_t entered_len;

    while(1){
        // Initialize the password buffer with the salt
        memcpy(password_buffer, serial_password_salt, SERIAL_PASSWORD_SALT_BYTES);

        print("Serial Password: ");

        // Have the user enter the password into the buffer, after the salt
        entered_len = ede_getstring_placeholder(getchar, putchar_raw, password_buffer + SERIAL_PASSWORD_SALT_BYTES, 64, '*');

        // Hash the buffer, including the salt, up to the end of the password the user typed
        fk_rom_hash_sha512(hash_buffer, password_buffer, entered_len + SERIAL_PASSWORD_SALT_BYTES);
        if(crypto_verify_64(hash_buffer, (const uint8_t *) serial_password_hash) == 0) break;
    }
}

// (addr len -- )
void hash_mem(edei32 *s, edeu16 *sp, volatile uint8_t* base, uint32_t window_size){
    if(*sp < 2){
        print("Must provide parameters\n");
        return;
    }
    uint32_t addr = (uint32_t) s[*sp - 2];
    uint32_t len  = (uint32_t) s[*sp - 1];
    *sp = *sp - 2;
    // Reading past the end of the memory-mapped window hits unmapped space
    // and hangs the core, so bound-check before touching `base`.
    if(addr >= window_size || len > window_size - addr){
        print("Out of window\n");
        return;
    }
    uint8_t hash_buffer[64];
    volatile uint8_t* start = base + addr;

    // fk_rom_hash_sha512 takes a non-volatile pointer. The cast is
    // safe: the hash reads each byte of the region exactly once, in
    // order, and nothing writes to the region meanwhile.
    fk_rom_hash_sha512(hash_buffer, (const uint8_t *) start, (uint64_t) len);

    for(int i=0; i<64; i++){
        print_hex(hash_buffer[i], 2);
    }

    print(" ");
}

void hash_hspi(edei32 *s, edeu16 *sp){
    // The window only works in MEMIO mode; manual mode is sticky after
    // any flashio worker call, so enable it explicitly here.
    spi_memio_enable(HSPI_CTL_ADDR);
    hash_mem(s, sp, (volatile uint8_t*) HSPI_BASE_ADDR, FLASH_WINDOW_SIZE);
}

void hash_cspi(edei32 *s, edeu16 *sp){
    // The window only works in MEMIO mode; manual mode is sticky after
    // any flashio worker call, so enable it explicitly here.
    spi_memio_enable(CSPI_CTL_ADDR);
    hash_mem(s, sp, (volatile uint8_t*) CSPI_BASE_ADDR, FLASH_WINDOW_SIZE);
}

void picosoc_benchmark_wrapper(){
    cmd_benchmark(1, 0);
}

void help(edei32 *s, edeu16 *sp){
    (void) s; // help takes no stack parameters
    (void) sp;
	print("help - print this help\n"
          "cfstat - print Configuration Flash controller status\n"
          "cfid - print Configuration Flash IDs\n"
          "cfcfg - set Configuration Flash controller config register (value -- )\n"
          "cfdump - dump Configuration Flash data (addr len -- )\n"
          "cfwrite - write to Configuration Flash ( d0 ... dn addr len -- )\n"
          "cfsr - print Configuration Flash Status Registers \n"
          "cfhash - SHA-512 hash Configuration Flash region (addr len -- )\n"
          "hfstat - print Host Flash controller status\n"
          "hfid - print Host Flash IDs\n"
          "hfcfg - set Host Flash controller config register (value -- )\n"
          "hfdump - dump Host Flash region (addr len -- )\n"
          "hfwrite - write to Host Flash ( d0 ... dn addr len -- )\n"
          "hfsr - print Host Flash Status Registers\n"
          "hfchiperase - erase Host Flash (danger!)\n"
          "hfhash - SHA-512 hash Host Flash region (addr len -- )\n"
          "romdump - dump Boot ROM (addr len -- )\n"
          "rng - print up to 256 whitened random bytes plus TRNG stats (n -- )\n"
          "ferr - dump UART Frame Error detection counter\n"
          "genpw - generate new password and salt configuration for flashkeeper_config.h\n"
          "benchmark - Run the PicoSoC CPU benchmark\n"
          "serprog - enter serprog mode\n"
          "\nThis shell has a Forth-like parameter stack - type .s to show its contents.\n"
          "Stack manipulation words (drop, swap, dup, over, rot), arithmetic words\n"
          "(+, -, *, /, /mod, mod), and basic output (., emit) are supported.\n");
}

void start_shell(){
    reg_uart_clkdiv = 10; // 1 Mbaud

	print("\n\nWelcome to Flashkeeper\n");

    ede_registerfn("help", help);

    // Configuration Flash controller commands
    ede_registerfn("cfstat", cmd_print_spi_state);
    ede_registerfn("cfid", cmd_read_flash_id);
    ede_registerfn("cfcfg", config_cspi);
    ede_registerfn("cfdump", dump_cspi);
    ede_registerfn("cfwrite", write_cspi);
    ede_registerfn("cfsr", cspi_print_sr);
    // cfchiperase is deliberately ommitted, as it would very directly entail "please brick immediately"
    ede_registerfn("cfhash", hash_cspi);

    // Host Flash controller commands
    ede_registerfn("hfstat", hspi_print_spi_state);
    ede_registerfn("hfid", hspi_read_flash_id);
    ede_registerfn("hfcfg", config_hspi);
    ede_registerfn("hfdump", dump_hspi);
    ede_registerfn("hfwrite", write_hspi);
    ede_registerfn("hfsr", hspi_print_sr);
    ede_registerfn("hfchiperase", hspi_chip_erase);
    ede_registerfn("hfhash", hash_hspi);

    // Boot ROM commands
    ede_registerfn("romdump", dump_brom);

    // System test commands
    ede_registerfn("rng", cmd_rng);
    ede_registerfn("ferr", cmd_ferr);
    ede_registerfn("benchmark", picosoc_benchmark_wrapper);

    // Configuration helpers
    ede_registerfn("genpw", generate_password);

    // Non-EDE modes
    ede_registerfn("serprog", serprog_command_loop);

    while(1){
        if(SERIAL_REQUIRE_PASSWORD){
            password_prompt();
        }else{
            print("WARNING! Serial password is disabled. Anyone can reconfigure this Flashkeeper.\n");
        }
        print("\n");

        print("Starting debug shell (Forth-like syntax - type help for help)...\n");

        ede_shell(getchar, putchar_raw);
    }
}

void main(){
    // for now, just start the shell at boot
    start_shell();
}

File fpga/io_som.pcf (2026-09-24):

# UART on DTX/DRX pins
set_io ser_rx     C5  # SOM GPIO2 - Debug UART RX
set_io ser_tx     B1  # SOM DTX - Debug UART TX

# SPI Flash
set_io flash_clk  D1  # Onboard SPI SCK
set_io flash_csb  C1  # Onboard SPI CS
set_io flash_io0  F1  # Onboard SPI MOSI
set_io flash_io1  E1  # Onboard SPI MISO

# reserved: 4-line SPI not brought out on the SoM (see top.v port list)
#set_io hspi_io2   B5  # SOM GPIO1 - host SPI IO2/WP (optional)
#set_io hspi_io3   F5  # SOM GPIO5 - host SPI IO3/HOLD (optional)
set_io hspi_io1   A5  # SOM GPIO0 - host SPI MISO
set_io hspi_io0   E5  # SOM GPIO3 - host SPI MOSI
set_io hspi_clk   D5  # SOM GPIO4 - host SPI CLK
set_io hspi_csb   A1  # SOM DRX - host SPI CS

# LED indicator (reused CDONE pin)
set_io led_n      D3  # Debug LED

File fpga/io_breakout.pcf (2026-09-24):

# iCE40UP5K-B-EVN (Lattice iCE40 UltraPlus Breakout Board, FPGA-UG-02001).
# Package pin numbers per the iCE40UP5K SG48 pin map (iCE40 UltraPlus data
# sheet, section 5.1); board headers per the EVN schematic:
#   J2  "HEADER B"    bank 0 general I/O - UART and host SPI
#   J3  "HEADER C"    bank 1/2 general I/O (unused)
#   J52 "HEADER A"    onboard flash SPI + RGB LEDs (unused)
#   U6  "PMOD SOCKET" onboard flash SPI and UART passthrough (unused)

# UART on J2 (HEADER B)
set_io ser_rx      26  # IOT_39A
set_io ser_tx      27  # IOT_38B

# Onboard SPI flash (N25Q032A1, 4 MB). SCK/SS are the package's dedicated
# SPI pins. SPI_SI/SPI_SO are named from the FPGA's perspective: SPI_SO is
# the FPGA's serial OUT (MOSI, into the flash), SPI_SI is the FPGA's serial
# IN (MISO, from the flash). This mapping is the one XIP worked with.
set_io flash_clk  15  # IOB_34A_SPI_SCK
set_io flash_csb  16  # IOB_35B_SPI_SS
set_io flash_io0  14  # IOB_32A_SPI_SO (MOSI)
set_io flash_io1  17  # IOB_33B_SPI_SI (MISO)

# Host SPI on the J2 (HEADER B) right-hand column (physically grouped)
set_io hspi_csb   36  # IOB_48B
set_io hspi_clk   42  # IOB_51A
set_io hspi_io0   38  # IOB_50B (MOSI)
set_io hspi_io1   28  # IOB_41A (MISO)

# LED indicator: RGB0 drives the blue LED (via R95)
set_io led_n      39  # RGB0

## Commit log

2025-01-21 Initial soldered flash adapter version
    [adapter_soldered.kicad_pcb, adapter_soldered.kicad_sch]
2025-01-21 Add KiCAD 3D renderings of chip adapter flex PCB
2025-02-05 Add hardware architecture/component selection/mechanical document, add CAD for flash chips, fix gitignore for Jekyll-generated pages
    [SOIC8.FCStd, SOIC8_Wide.FCStd, adapter_soldered.kicad_pcb]
2025-02-14 Add WP-only flash adapters, add component and PCB for SOIC8-W (wide) flash chips, documentation
    [SOIC8.FCStd, SOIC8_Wide.FCStd, adapter_soldered.kicad_pcb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]
2025-04-06 Initial CAD for soldered adapter on WSON packages, WSON package validation model
    [SOIC8.FCStd, WSON.FCStd]
2025-04-07 Add an "interposer block" between the WSON package and the chip adapter, holding the chip adapter's legs down against the sides of the WSON
    [SOIC8.FCStd, WSON.FCStd]
2025-07-11 Import latest PCB changes from out-of-tree flashkeeper_hw repo
    [adapter_soldered.kicad_pcb, adapter_soldered.kicad_sch, dummy.kicad_pcb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]
2026-05-14 Add KiCAD source for Flashkeeper FPGA SoM and its production panel and its associated component libraries. Add basic 3D models for some of the chip packages used. Minimal initial PicoSoC/PicoRV32 con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
    [Basic_AT25DF041-UUN.step, Basic_AT25DF041B.FCStd, Basic_RV-3028-C8.FCStd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]
2026-05-31 Add KiCAD for Flashkeeper FPGA module flex PCB, for use with the previously-committed FPGA SoM, and for a USB programming/configuration/debug tool for use with it. Various new component library symbo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
    [1-2328702-0.STEP, CMT-322-65-SMT-TR.step, FlashkeeperFPGASoM.step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]
2026-05-31 Update documentation/website for new FPGA hardware, document cables
2026-09-25 Remove old unbuffered simpleuart.v. Detect password prompts in verify_rom.py. Fix stack data address calculation in main.c write_spi's flashio_call. Re-initialize stack pointer in firmware entry.s.
    [ede_programmer.py, main.c, verify_rom.py]
2026-09-25 hw/ - DFM/manufacturability improvements for FPGA flex PCB variant. New extra-wide adapter_soldered/breakout_wson for WSON 8x6.
    [adapter_soldered.kicad_pcb, adapter_soldered.kicad_sch, fpga.kicad_pcb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]
